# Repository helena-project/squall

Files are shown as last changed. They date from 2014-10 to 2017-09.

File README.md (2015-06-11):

Squall
======

Squall is a low cost, 1 inch round BLE sensor tag based on the Nordic
nRF51822 BLE / Cortex M0 SoC. It is designed to be the basis for experimenting
with BLE tag platforms.

### Squall Versions

Squall comes in two flavors: a stripped down version with only the essentials
that has a raw cost just over $5. This includes the SoC, an antenna, expansion
headers, and a battery clip. This version is targeted towards sensor deployments
where a low cost per device is essential to permit larger deployments.

The second version adds USB support so that the nRF51822 can be programmed
with a serial bootloader, and adds a reset button and 32 kHz crystal. This
design is intended to be easier to get started with as it only requires
a USB connection to program. It also supports a rechargeable battery that
will charge over USB.

### Hardware Tools

To aid developing with Squall, there is a
[breakout board](/hardware/squall-breakout/rev_b) that makes it easier to debug
signals and program the board.

To program Squall over JTAG, there is an
[adapter board](https://github.com/lab11/nrf51-tools/tree/master/hardware/jlink_to_tag/rev_b)
that adapts the J-Link JTAG 20-pin header to the much smaller
[tag connect](http://www.tag-connect.com/catalog/6) header.

Daughter Boards
---------------

Squall is designed to be a base BLE platform with shields on top. A couple
shields have been developed:

- [Rain](/hardware/rain) - Sensing platform for wearable exploration.
- [BLEES](https://github.com/lab11/blees) - Environmental sensing platform.

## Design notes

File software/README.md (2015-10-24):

Setting Up The nRF51822
=======================

This guide explains how to get going with running code on nRF51822 based
platforms.

Setup
-----

1. Make sure you have the [arm-none-eabi-gcc](https://launchpad.net/gcc-arm-embedded)
toolchain. You just need the binaries for your platform.

1. Get the [Segger flashing tools](http://www.segger.com/jlink-software.html)
for your platform.

Install an Application
----------------------

1. Now compile and load the application code. This will also
load the softdevice onto the nRF if needed.

        make flash

    For platforms that are not Squall:

        make flash TARGET=nrf6310

    Choices:

        NRF6310
        PCA10000
        PCA10001
        PCA10003
        SQUALL
        
    If you have multiple JLink devices, you can specify which one
    to use like this:
    
        SEGGER_SERIAL=<serial num> make flash

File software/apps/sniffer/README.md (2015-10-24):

Sniffer BLE App
===============

This app blinks the LED everytime it receives an advertisement.

It uses the central role on the S120 softdevice.

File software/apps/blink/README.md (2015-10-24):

Blink App
=========

Blink the LED on Squall.

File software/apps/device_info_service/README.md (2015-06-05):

Service Example
===============

This is a simple base application that continually advertises and has a device 
information service.

This app should be a good starting point for providing a service.

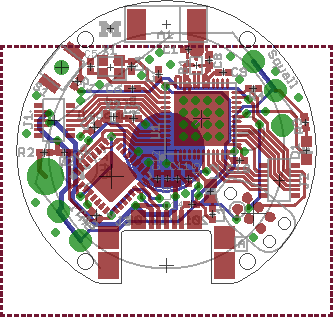
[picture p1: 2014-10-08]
hardware/squall/rev_a/squall_pcb.png

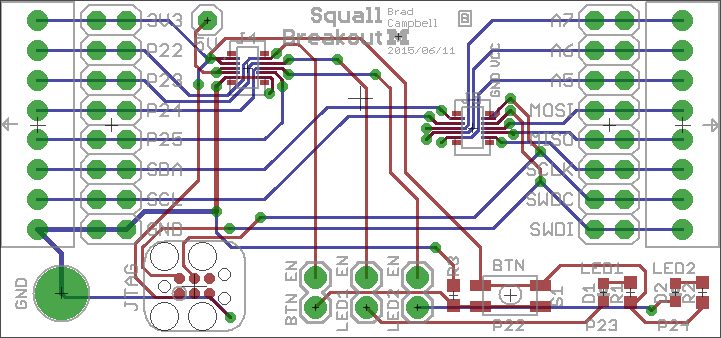
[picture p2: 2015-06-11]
hardware/squall-breakout/rev_b/squall-breakout_pcb.png

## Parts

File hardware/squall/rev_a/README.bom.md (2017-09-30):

Squall BOM
==========

Squall comes in two possible configurations, A and B. Configuration A is
cheaper. It does not include any USB integration, just the Bluetooth.

The files `squall_bom.LEGACY` present these configurations as priced out
in 2014 with the original design. A handful of passives have been obsoleted
since then, they are not hard to replace.

The files `squall_bom.2017-09.ConfigurationB` are an updated BOM from a
manufacturing run in fall '17 for the full-featured configuration.

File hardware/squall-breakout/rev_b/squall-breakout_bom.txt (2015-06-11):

# Bill of Materials
# Converted from squall-breakout_bom.xlsx
# Generated by bom_to_text.py

Qty  Value                   Device                  Package            Parts         Description                                                    DIGIKEY       MOUSER               NEWARK
2                            LED0603                 LED-0603           D1, D2        LEDs                                                                                              
2    SQUALL_HEADER           SQUALL_HEADER           SQUALL_HEADER      J1            Header for a sensor board on top of the Squall BLE tag board.  H11617CT-ND                        
2                            PINHD-2X8               2X08               J2, J3        PIN HEADER                                                     609-3364-ND   649-68602-116HLF     20M2833
2    HIROSE-DF40C-10DP-0.4V  HIROSE-DF40C-10DP-0.4V  2X5/SMD/0.4MM      J4, J5        DF40 Series Header - 0.4MM Pitch                               H11616CT-ND   798-DF40C10DP0.4V51  68X2585
1                            PINHD-1X1               1X01               J6            PIN HEADER                                                     A107006-ND                         
2    SCREW-TERMINAL_8_0.100  SCREW-TERMINAL_8_0.100  CONN_BLOCK_8       J7, J8        8x 0.100 in screw terminal block                               277-1279-ND   651-1725711          71C4111
3                            JUMPER-2PTH             1X02               J9, J10, J11  Jumper                                                         3M9447-ND                          
2    470                     R-US_R0603              R0603              R1, R2        RESISTOR, American symbol                                                                         
1    10k                     R-US_R0603              R0603              R3            RESISTOR, American symbol                                                                         
1    EVQP2                   EVQP2                   EVQP2              S1            SWITCH TACTILE SPST-NO 0.02A 15V                               P11084SCT-ND                       
1    TEST_POINT_0.112IN      TEST_POINT_0.112IN      TESTPOINT_0.112IN  TP1           Solder terminal, turreted                                                                         40F6015

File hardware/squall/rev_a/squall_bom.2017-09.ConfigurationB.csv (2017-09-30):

# Bill of Materials
# Converted from {}
# Generated by bom_to_text.py
#
Qty | Parts | Do Not Insert | Can Substitute? | Value | Device | Package | DESCRIPTION | DIGIKEY | MANUFACTURER | MOUSER | MPN | NEWARK | OC_FARNELL | OC_NEWARK | RICHARDSON_RFPD
1 | A1 |  |  | FRACTUS-2.4GHZ-FR05-S1-N-0-102 | FRACTUS-2.4GHZ-FR05-S1-N-0-102 | FRACTUS-ANTENNA-FR05-S1-N-0-102 | Fractus Compact Reach XtendTM chip antenna is engineered specifically for Bluetooth, |  | RichardsonRFPD |  | FR05-S1-N-0-102 |  |  |  | FR05-S1-N-0102B
1 | B1 |  |  | BAL-NRF01D3 | BAL-NRF01D3 | BAL-NRF01D3 | 50 ohm nominal input / conjugate match balun to nRF51422-QFAA, | 497-13637-1-ND |  | 511-BAL-NRF01D3 | BAL-NRF01D3
1 | BAT1 | X |  | BAT-HLD-002-THM | BAT-HLD-002-THM | BAT-HLD-002-THM | RETAINER BATT CR2016 PC PINS | BAT-HLD-002-THM-ND |  | 712-BAT-HLD-002-THM
1 | BAT2 | X |  | ML-2020/H1C | ML-2020/H1C | ML-2020/H1C | BATT LITH COIN 3V RECHARGE PINS 45mAh | P047-ND |  | 658-ML-2020/H1CN
1 | C1 |  | Y | 0.8pF | CAPACITOR | 0402_CAP | CAP CER 0.8PF 50V C0G/NP0 0402 | 490-6269-1-ND | Murata |  | GRM1555C1HR80BA01D
4 | C2, C3, C4, C5 |  | Y | 12pF | CAPACITOR | 0402_CAP | CAP CER 12PF 50V C0G/NP0 0402 | 490-6197-1-ND | Murata |  | GRM1555C1H120GA01D
2 | C6, C7 |  | Y | 1nF | CAPACITOR | 0402_CAP | CAP CER 1000PF 50V X7R 0402 | 490-1303-1-ND | Murata |  | GRM155R71H102KA01D
1 | C8 |  | Y | 2.2nF | CAPACITOR | 0402_CAP | CAP CER 2200PF 25V 10% X7R 0402 | 490-5419-1-ND | Murata |  | GRM155R71E222KA01D
1 | C9 |  | Y | 47nF | CAPACITOR | 0402_CAP | CAP CER 0.047UF 16V X7R 0402 | 445-1264-1-ND | TDK |  | C1005X7R1C473K050BC
4 | C10, C11, C12, C13 |  | Y | 0.1uF | CAPACITOR | 0402_CAP | CAP CER 0.1UF 10V X5R 0402 | 490-1318-1-ND | Murata |  | GRM155R61A104KA01D
1 | C14 |  | Y | 1uF | CAPACITOR | 0402_CAP | 1µF ±10% 6.3V Ceramic Capacitor X7R 0402 (1005 Metric) | 1276-1513-1-ND | Samsung |  | CL05B105KQ5NQNC
1 | C15 |  | Y | 4.7uF | CAPACITOR | 0402_CAP | CAP CER 4.7UF 6.3V X5R 0402 | 445-5947-1-ND | TDK |  | C1005X5R0J475K050BC
1 | D1 |  | Y | BLUE | LED0603 | LED-0603 | LED BLUE CLEAR 0603 SMD | 160-1827-1-ND | Lite-On |  | LTST-C193TBKT-5A
1 | D2 |  | Y | DIODE | DIODE | 0402_DIODE | DIODE SCHOTTKY 30V 0.1A 0402 | 641-1271-1-ND | Comchip | 750-CDBQR0130L | CDBQR0130L
2 | J1, J2 |  |  | HIROSE-DF40C-10DP-0.4V | HIROSE-DF40C-10DP-0.4V | 2X5/SMD/0.4MM | DF40 Series Header - 0.4MM Pitch | H11616CT-ND |  | 798-DF40C10DP0.4V51 | DF40C-10DP-0.4V(51) | 68X2585
1 | J3 |  |  | MICRO_USB_B_JST_MC5BR3-M404-4S | MICRO_USB_B_JST_MC5BR3-M404-4S | USB_MICRO_B-JST-MC5BR3-M404-4S-TB | Micro USB B mid mount | 455-2567-2-ND |  | 53X3655 | UB-MC5BR3-M404-4S-TB NMP
1 | J4 | X |  | TC2030-JLINK-NL | TC2030-JLINK-NL | TC2030-IDC-NL |  | - | - | - | -
1 | L1 |  |  | 15nH | INDUCTOR0402 | 0402_CAP | FIXED IND 15NH 320MA 460 MOHM | 587-1521-1-ND | Taiyo Yuden |  | HK100515NJ-T
1 | L2 |  |  | 10uH | INDUCTOR0603 | 0603_CAP | FIXED IND 10UH 50MA 900 MOHM SMD | 490-4025-1-ND | Murata |  | LQM18FN100M00D
1 | L3 |  | Y |  | INDUCTOR0402 | 0402_CAP | FERRITE BEAD 30 OHM 0402 1LN | 445-2979-1-ND | TDK Corporation |  | MPZ1005S300CT000
2 | R1, R2 |  | Y | 150 | RESISTOR | 0402_RES | RES SMD 150 OHM 1% 1/16W 0402 | RHM150CDCT-ND | Rohm |  | MCR01MRTF1500
1 | R3 |  | Y | 1k | RESISTOR | 0402_RES | RES SMD 1K OHM 5% 1/16W 0402 | 1276-4376-1-ND | Samsung |  | RC1005J102CS
1 | R4 |  | Y | 12k | RESISTOR | 0402_RES | RES SMD 12K OHM 1% 1/16W 0402 | 1276-4122-1-ND | Samsung |  | RC1005F123CS
1 | S1 |  |  | B3U-3000P-B | B3U-3000P-B | B3U-3000P-B |  | SW1256CT-ND |  |  | B3U-3000P-B
1 | U1 |  |  | NRF51822QF | NRF51822QF | QFN-48-6MM | Multiprotocol Bluetooth® 4.0 low energy/2.4 GHz RF SoC | 1490-1032-1-ND | Nordic | 949-NRF51822-QFAB-R7 | NRF51822-QFAB-R7
1 | U2 |  |  | FT232RQ | FT232RQ | QFN32 | Source: http://www.ftdichip.com/Documents/DataSheets/DS_FT232R_v104.pdf |  |  |  | FT232RQ |  | 1146033 | 91K9919
1 | X1 |  |  | 16MHz | TXC-8Y | TXC-8Y | CRYSTAL 16.0000MHZ 8PF SMD | 887-2003-1-ND | TXC |  | 8Y-16.000MAAV-T
1 | X2 |  |  | ABS05-32.768KHZ-9-T | ABS05-32.768KHZ-9-T | ABS05 | 32.768kHz Crystal | 535-11897-1-ND
 | Note: Any part marked "Can Substitue" can be substituted for any equal size/value parts

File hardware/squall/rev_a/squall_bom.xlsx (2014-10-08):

Qty | Value | Device | Package | Parts | Description | DIGIKEY | MOUSER | NEWARK | RICHARDSON_RFPD | Price Each (1000) | Quantity (A) | Cost (A) | Quantity (B) | Cost (B)
1 | FRACTUS-2.4GHZ-FR05-S1-N-0-102 | FRACTUS-2.4GHZ-FR05-S1-N-0-102 | FRACTUS-ANTENNA-FR05-S1-N-0-102 | A1 | Fractus Compact Reach XtendTM chip antenna is engineered specifically for Bluetooth, |  |  |  | FR05-S1-N-0102B | 0.63 | 1 | 0.63 | 1 | 0.63
1 | BAL-NRF01D3 | BAL-NRF01D3 | BAL-NRF01D3 | B1 | 50 ohm nominal input / conjugate match balun to nRF51422-QFAA, | 497-13637-1-ND | 511-BAL-NRF01D3 |  |  | 0.337 | 1 | 0.337 | 1 | 0.337
1 | BAT-HLD-002-THM | BAT-HLD-002-THM | BAT-HLD-002-THM | BAT1 | RETAINER BATT CR2025/2032 PC PIN | BAT-HLD-001-THM-ND |  |  |  | 0.20125 | 1 | 0.20125 |  | 0
1 | ML-2020/H1C | ML-2020/H1C | ML-2020/H1C | BAT2 | BATT LITH COIN 3V RECHARGE PINS 45mAh | P047-ND | 658-ML-2020/H1CN |  |  | 1.4025 |  | 0 | 1 | 1.4025
1 | 0.8pF | CAPACITOR | 0402_CAP | C1 | 0402 Capacitor | 490-6269-1-ND |  |  |  | 0.0127 | 1 | 0.0127 | 1 | 0.0127
4 | 12pF | CAPACITOR | 0402_CAP | C2, C3, C4, C5 | 0402 Capacitor | 490-6197-1-ND |  |  |  | 0.0178 | 2 | 0.0356 | 4 | 0.0712
2 | 1nF | CAPACITOR | 0402_CAP | C6, C7 | 0402 Capacitor | 490-1303-1-ND |  |  |  | 0.01009 | 2 | 0.02018 | 2 | 0.02018
1 | 2.2nF | CAPACITOR | 0402_CAP | C8 | 0402 Capacitor | 490-5419-1-ND |  |  |  | 0.0127 | 1 | 0.0127 | 1 | 0.0127
1 | 47nF | CAPACITOR | 0402_CAP | C9 | 0402 Capacitor | 445-1264-1-ND |  |  |  | 0.0151 | 1 | 0.0151 | 1 | 0.0151
1 | 0.1uF | CAPACITOR | 0402_CAP | C10 | 0402 Capacitor | 445-4952-1-ND |  |  |  | 0.0136 | 1 | 0.0136 | 1 | 0.0136
3 | 0.1uF | CAPACITOR | 0402_CAP | C11, C12, C13 | 0402 Capacitor | 490-1318-6-ND |  |  |  | 0.01 |  | 0 | 3 | 0.03
1 | 1uF | CAPACITOR | 0402_CAP | C14 | 0402 Capacitor | 1276-1513-1-ND |  |  |  | 0.058 |  | 0 | 1 | 0.058
1 | 4.7uF | CAPACITOR | 0402_CAP | C15 | 0402 Capacitor | 445-5947-1-ND |  |  |  | 0.122 |  | 0 | 1 | 0.122
1 | BLUE | LED0603 | LED-0603 | D1 | LED 468NM BLUE CLEAR 0603 SMD | 160-1647-1-ND |  |  |  | 0.0925 | 1 | 0.0925 | 1 | 0.0925
1 | DIODE | DIODE | 0402_DIODE | D2 | DIODE SCHOTTKY 30V 0.1A 0402 | 641-1271-1-ND | 750-CDBQR0130L |  |  | 0.11 |  | 0 | 1 | 0.11
2 | HIROSE-DF40C-10DP-0.4V | HIROSE-DF40C-10DP-0.4V | 2X5/SMD/0.4MM | J1, J2 | DF40 Series Header - 0.4MM Pitch | H11616CT-ND | 798-DF40C10DP0.4V51 | 68X2585 |  | 0.38815 | 2 | 0.7763 | 2 | 0.7763
1 | MICRO_USB_B_JST_MC5BR3-M404-4S | MICRO_USB_B_JST_MC5BR3-M404-4S | USB_MICRO_B-JST-MC5BR3-M404-4S-TB | J3 | Micro USB B mid mount | 455-2567-2-ND | 53X3655 |  |  | 0.60558 |  | 0 | 1 | 0.60558
1 | 15nH | INDUCTOR0402 | 0402_CAP | L1 | INDUCTOR HI FREQ 15NH 5% 0402 | 587-1521-1-ND |  |  |  | 0.034 | 1 | 0.034 | 1 | 0.034
1 | 10uH | INDUCTOR0603 | 0603_CAP | L2 | INDUCTOR 10UH 50MA 0603 | 490-4025-1-ND |  |  |  | 0.07434 | 1 | 0.07434 | 1 | 0.07434
1 |  | INDUCTOR0402 | 0402_CAP | L3 | FERRITE CHIP 30 OHM 1.7A 0402 | 445-2979-1-ND |  |  |  | 0.0334 |  | 0 | 1 | 0.0334
2 | 150 | RESISTOR | 0402_RES | R1, R2 | Resistor | RHM150CDCT-ND |  |  |  | 0.00933 |  | 0 | 2 | 0.01866
1 | 1k | RESISTOR | 0402_RES | R3 | Resistor | RHM1.0KCECT-ND |  |  |  | 0.00933 | 1 | 0.00933 | 1 | 0.00933
1 | 12k | RESISTOR | 0402_RES | R4 | Resistor | RHM12.0KCDCT-ND |  |  |  | 0.00933 | 1 | 0.00933 | 1 | 0.00933
1 | B3U-3000P-B | B3U-3000P-B | B3U-3000P-B | S1 | SWITCH TACTILE SPST-NO 0.05A 12V | SW1256CT-ND |  |  |  | 0.66414 |  | 0 | 1 | 0.66414
1 | NRF51822QF | NRF51822QF | QFN-48-6MM | U1 | Multiprotocol Bluetooth® 4.0 low energy/2.4 GHz RF SoC 256K | 1490-1031-1-ND |  |  |  | 2.31 | 1 | 2.31 | 1 | 2.31
1 | FT232RQ | FT232RQ | QFN32 | U2 | IC USB FS SERIAL UART 32-QFN | 768-1008-1-ND |  | 91K9919 |  | 3.301 |  | 0 | 1 | 3.301
1 | 16MHz | TXC-8Y | TXC-8Y | X1 | CRYSTAL 16MHZ 8PF SMD | 887-2003-1-ND |  |  |  | 0.782 | 1 | 0.782 | 1 | 0.782
1 | ABS05-32.768KHZ-9-T | ABS05-32.768KHZ-9-T | ABS05 | X2 | 32.768kHz Crystal | 535-11897-1-ND |  |  |  | 1.061 |  | 0 | 1 | 1.061
 |  |  |  |  | BATTERY LITHIUM COIN 3V 20MM CR2032 | P189-ND |  |  |  | 0.15579 | 1 | 0.15579
 |  |  |  |  |  |  |  |  |  |  |  | 5.52172 |  | 12.60656

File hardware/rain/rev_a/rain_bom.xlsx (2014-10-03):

Qty | Value | Device | Package | Parts | Description | DIGIKEY | PRECISION_MICRODRIVES
1 | 10nF | CAPACITOR | 0402_CAP | C1 | 0402 Capacitor | 490-1312-1-ND
7 | 0.1uF | CAPACITOR | 0402_CAP | C2, C3, C4, C5, C6, C7, C8 | 0402 Capacitor | 490-1318-1-ND
1 | 10uF | CAPACITOR | 0402_CAP | C9 | 0402 Capacitor | 445-8919-1-ND
1 | 22uF | CAP_POL0603 | CAP0603 | C10 | 0603 Tantalum Capacitor | 511-1493-1-ND
3 | SFH4056 | SFH4056 | SFH4056 | D1, D2, D3 | LED IR EMITTER 850NM | 475-3042-1-ND
1 | DIODE | DIODE | 0402_DIODE | D4 |  | 641-1277-1-ND
2 | SQUALL_HEADER | SQUALL_HEADER | SQUALL_HEADER | J1 | Header for a sensor board on top of the Squall BLE tag board. | H11617CT-ND
1 |  | PINHD-2X2 | 2X02 | J2 | PIN HEADER | 609-3201-ND
1 | 308-100 | 308-100 | 308-100 | M1 | Pico Vibe |  | 308-100
1 | ROHM-NPN-2SC5662 | ROHM-NPN-2SC5662 | VMT3 | Q1 |  | 2SC5662T2LPCT-ND
1 | 30 | RESISTOR0402_RES | 0402_RES | R1 | Resistor | RHM30CECT-ND
1 | 33 | RESISTOR0402_RES | 0402_RES | R2 | Resistor | RHM33CECT-ND
1 | 1k | RESISTOR0402_RES | 0402_RES | R3 | Resistor | RHM1.0KCECT-ND
2 | 10k | RESISTOR0402_RES | 0402_RES | R4, R5 | Resistor | RHM10.0KCDCT-ND
1 | LPS331AP | LPS331AP | HCLGA-16/3MM | U1 | IC PRESSURE SENSOR PIEZO 16HCLGA | 497-12927-1-ND
1 | MPU-9250 | MPU-9250 | QFN-24/3MM | U2 | GYRO/ACCEL/COMPASS/9-AXIS | 1428-1019-1-ND
1 | SI1147 | SI1147 | QFN-10/2MM | U3 | SENSOR DGTL UV INDEX 10QFN | 336-2624-1-ND
1 | SI7021 | SI7021 | DFN-6/3MM | U4 | IC TEMP SENSOR RH 2% DFN | 336-2542-1-ND

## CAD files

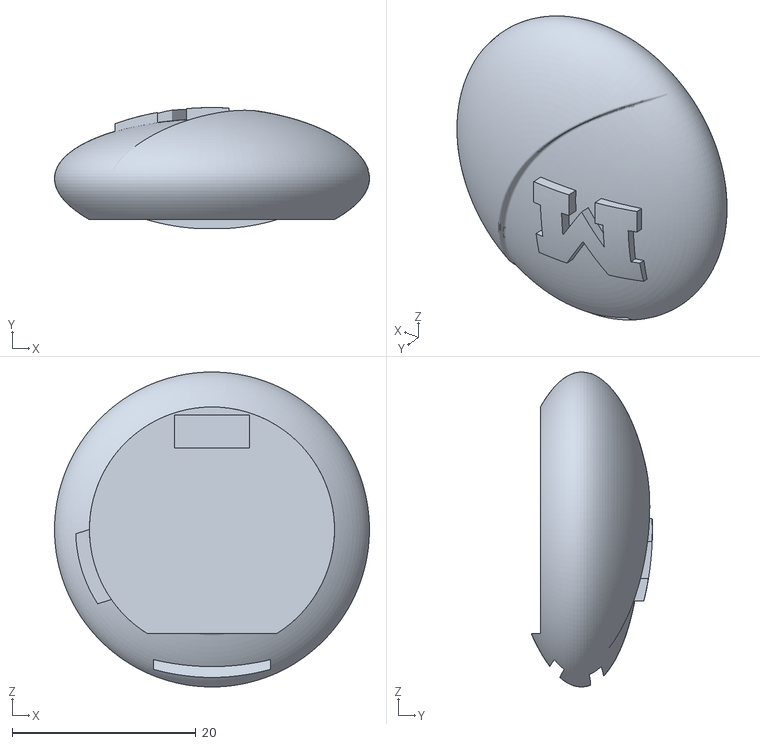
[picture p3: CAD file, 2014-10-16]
cases/squall_base_case_top_5.stl
34.3 x 13.2 x 34.3

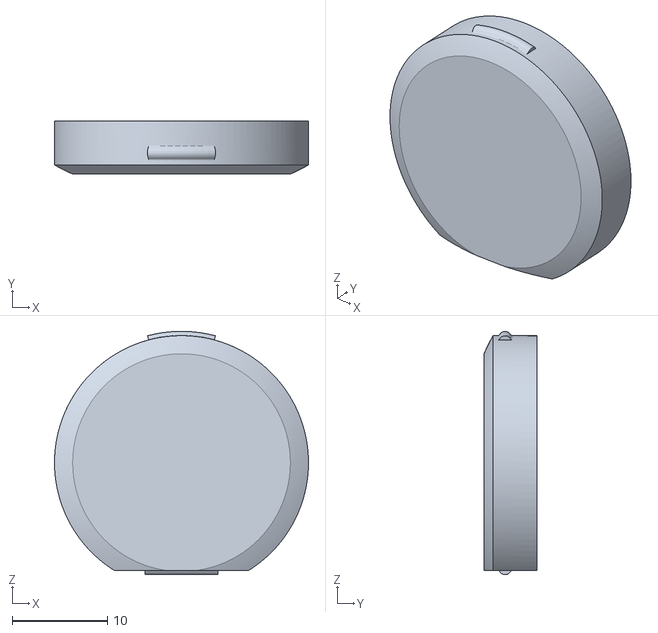
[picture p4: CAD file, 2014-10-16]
cases/squall_base_case_bottom_5.stl
26.7 x 5.59 x 25.5

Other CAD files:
cases/case.ipt
cases/case_bottom.ipt

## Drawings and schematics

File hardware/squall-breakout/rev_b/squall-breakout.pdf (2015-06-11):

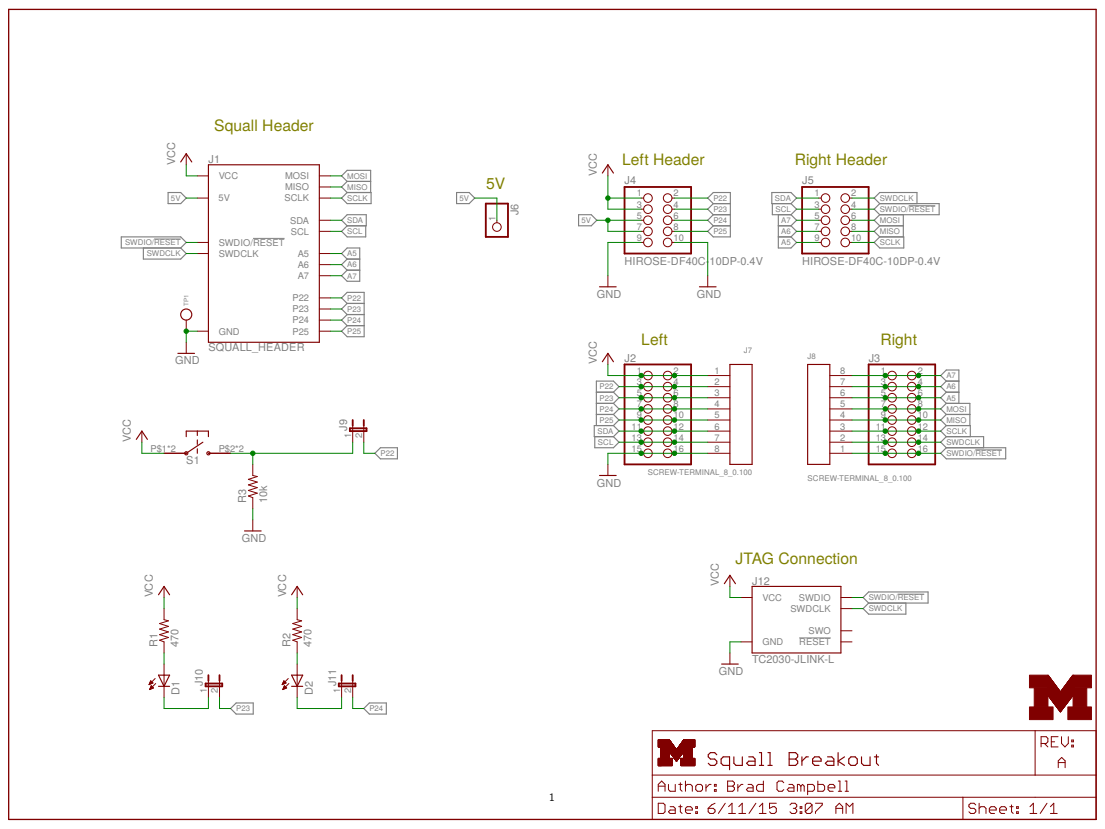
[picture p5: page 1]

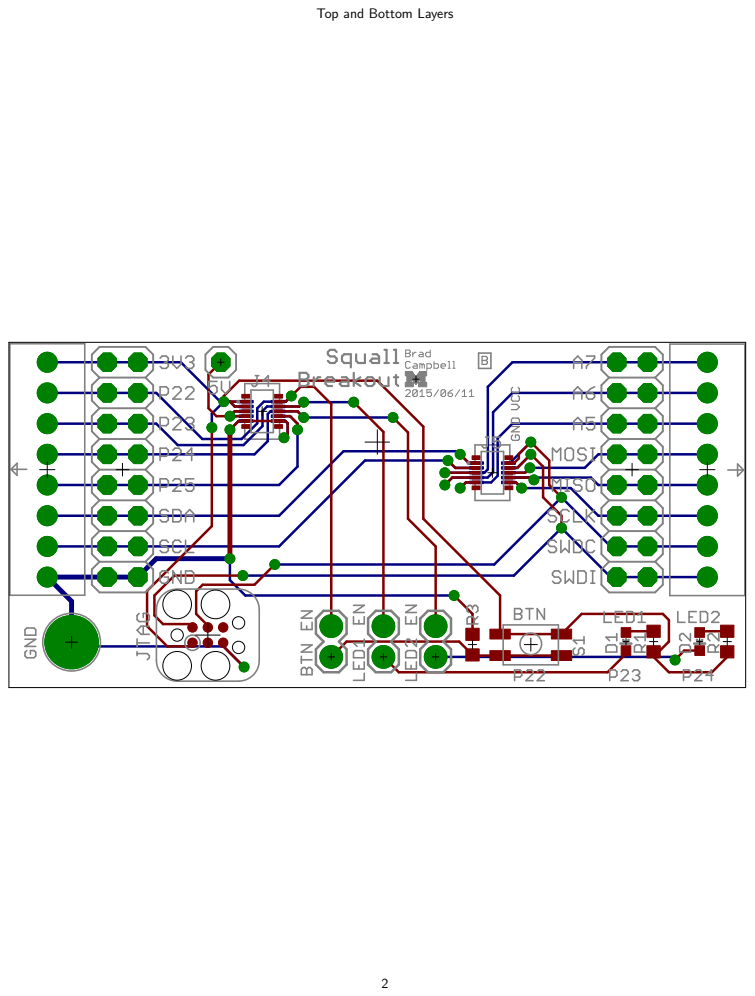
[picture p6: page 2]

Top and Bottom Layers

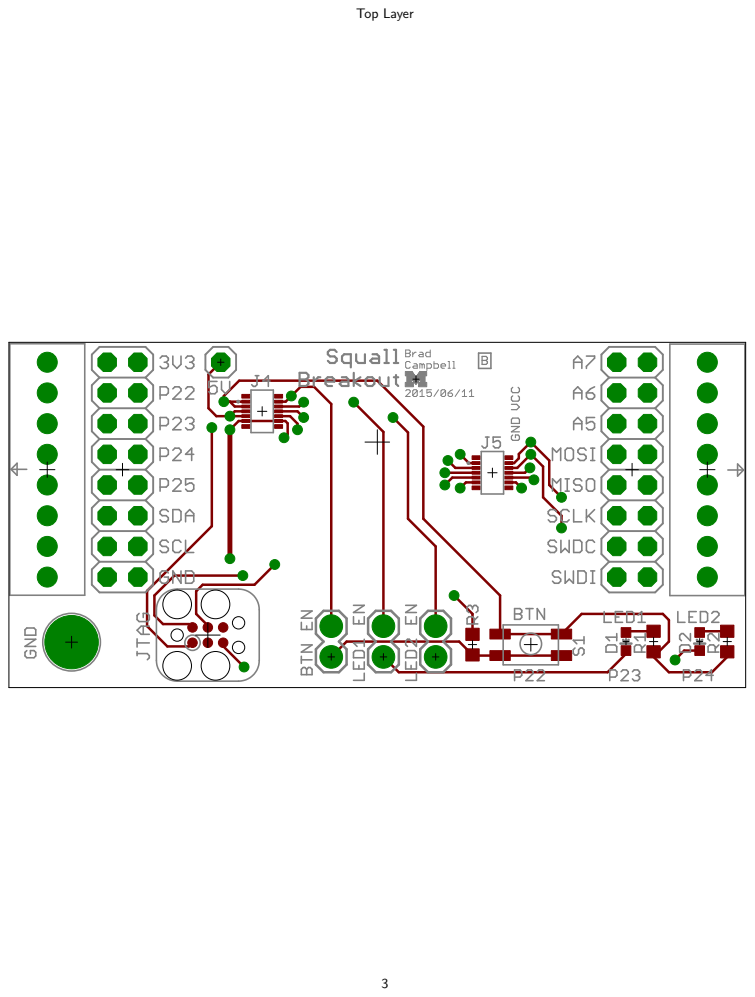
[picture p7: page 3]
Top Layer

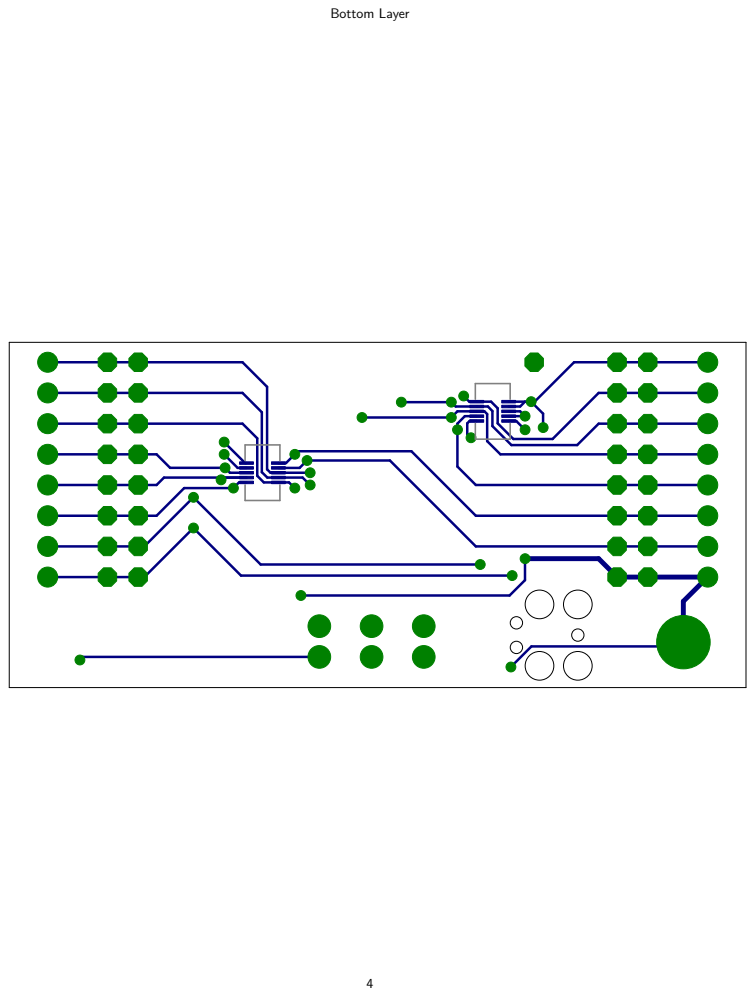
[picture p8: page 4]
Bottom Layer

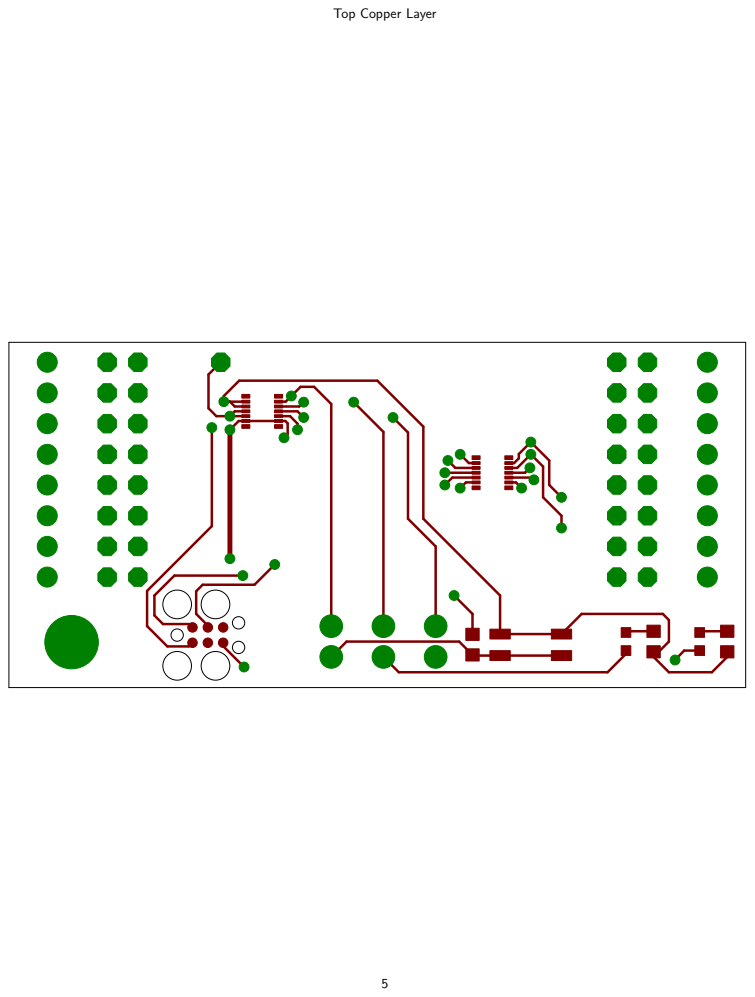
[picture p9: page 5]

Top Copper Layer

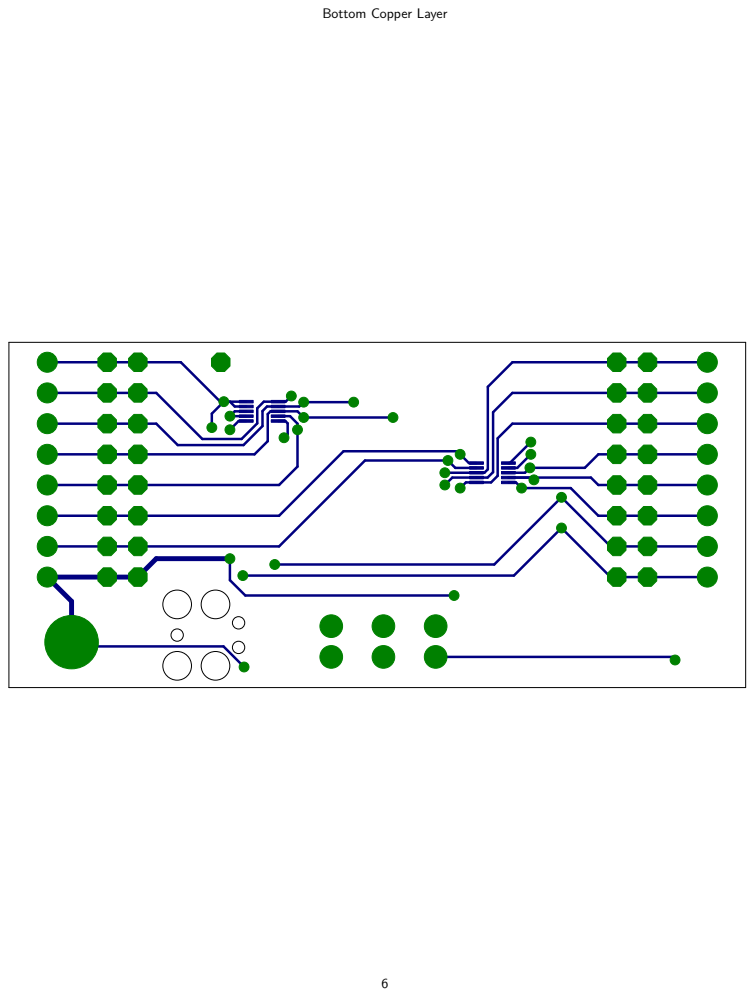
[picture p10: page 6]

Bottom Copper Layer

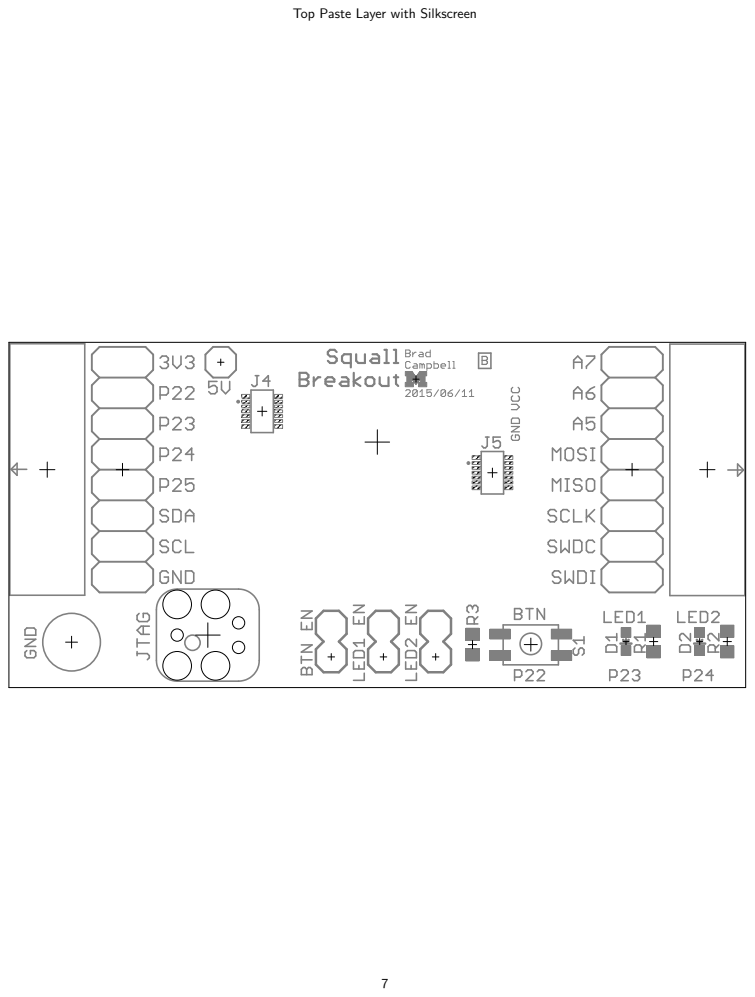
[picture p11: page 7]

Top Paste Layer with Silkscreen

Bottom Paste Layer with Silkscreen

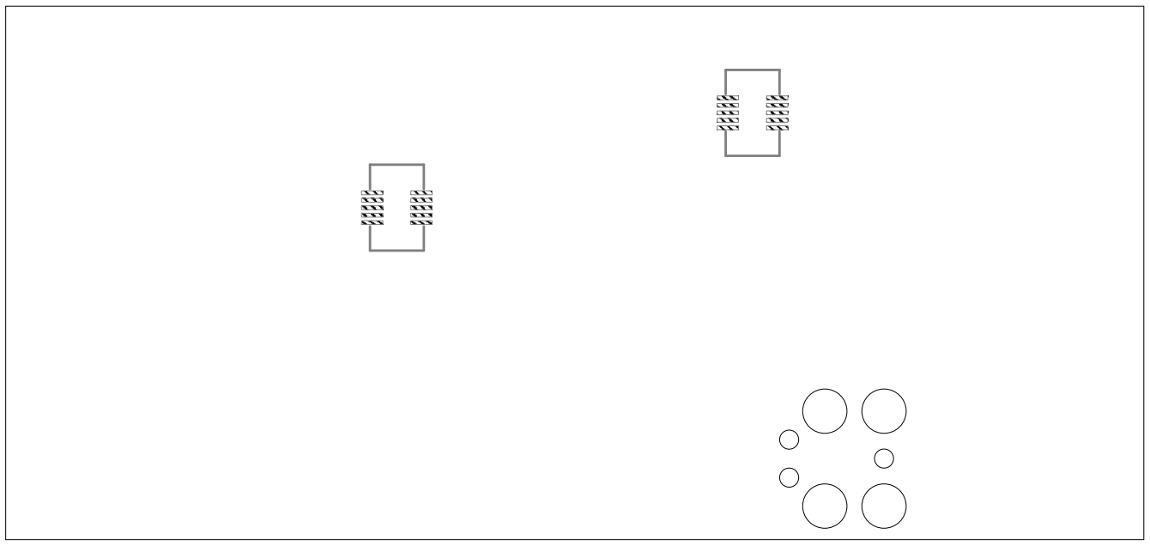
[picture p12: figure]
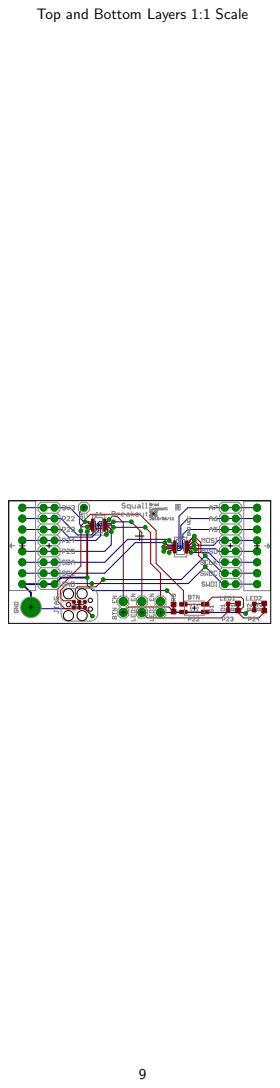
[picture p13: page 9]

Top and Bottom Layers 1:1 Scale

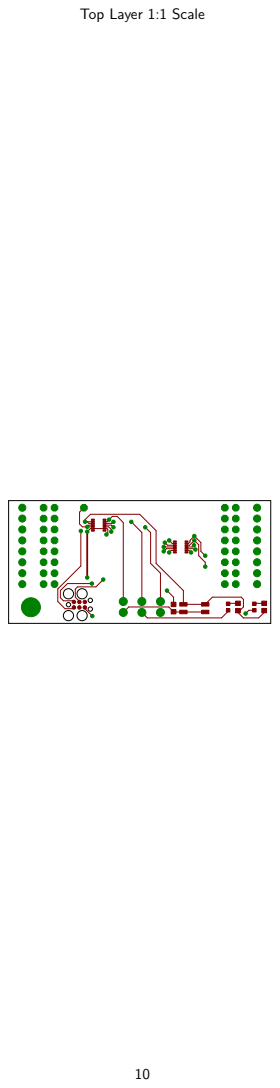
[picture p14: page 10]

Top Layer 1:1 Scale

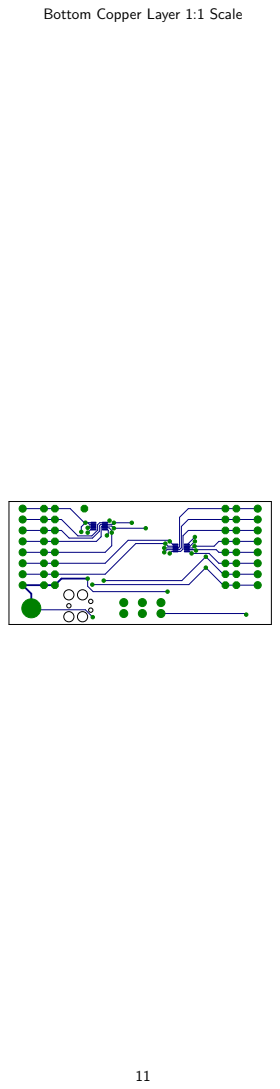
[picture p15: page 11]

Bottom Copper Layer 1:1 Scale

### Sheet1

Qty Value | Device | Package | Parts
2 | LED0603 | LED-0603 | D1, D2
2 SQUALL_HEADER | SQUALL_HEADER | SQUALL_HEADER | J1
2 | PINHD-2X8 | 2X08 | J2, J3
2 HIROSE-DF40C-10DP-0.4V | HIROSE-DF40C-10DP-0.4V | 2X5/SMD/0.4MM | J4, J5
1 | PINHD-1X1 | 1X01 | J6
2 SCREW-TERMINAL_8_0.100 SCREW-TERMINAL_8_0.100 CONN_BLOCK_8 | J7, J8
3 | JUMPER-2PTH | 1X02 | J9, J10, J11
2 470 | R-US_R0603 | R0603 | R1, R2
1 10k | R-US_R0603 | R0603 | R3
1 EVQP2 | EVQP2 | EVQP2 | S1
1 TEST_POINT_0.112IN | TEST_POINT_0.112IN | TESTPOINT_0.112IN TP1

### Sheet1

Description | DIGIKEY | MOUSER
LEDs
Header for a sensor board on top of the Squall BLE tag board. H11617CT-ND
PIN HEADER | 609-3364-ND | 649-68602-116HLF
DF40 Series Header - 0.4MM Pitch | H11616CT-ND 798-DF40C10DP0.4V51
PIN HEADER | A107006-ND
8x 0.100 in screw terminal block | 277-1279-ND | 651-1725711
Jumper | 3M9447-ND
RESISTOR, American symbol
RESISTOR, American symbol
SWITCH TACTILE SPST-NO 0.02A 15V | P11084SCT-ND
Solder terminal, turreted

### Sheet1

NEWARK

20M2833
68X2585

71C4111

40F6015

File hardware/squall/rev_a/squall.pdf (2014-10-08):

Left Header | Right Header

## JTAG Connection

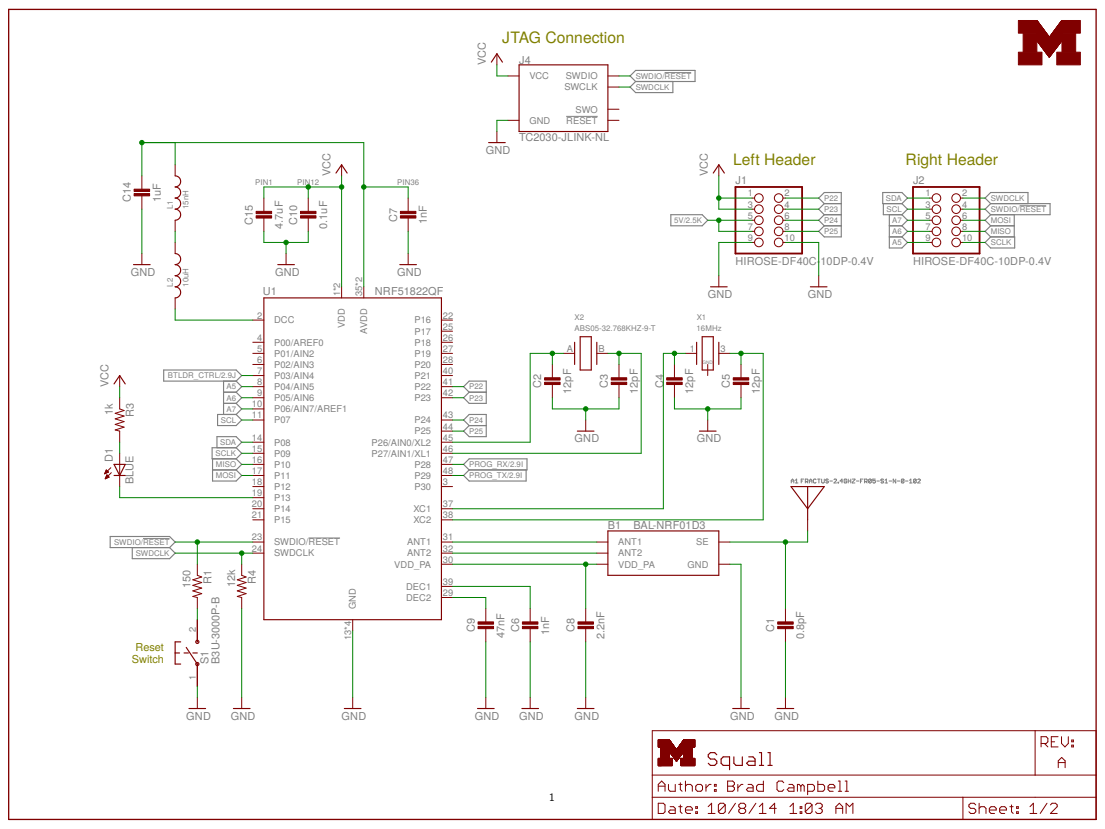
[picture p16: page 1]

## Batteries


Note: Only one battery can be connected at a time.
If BAT1 is connected, do not populate D2 or R2.
If BAT2 is connected, D2 and R2 must be populated for recharging.

FTDI Circuit for UART Programming and Communication


Top and Bottom Layers

Top Layer

Bottom Layer


Top Copper Layer


Bottom Copper Layer


Top Paste Layer with Silkscreen


Bottom Paste Layer with Silkscreen


Top and Bottom Layers 1:1 Scale

Top Layer 1:1 Scale


Bottom Copper Layer 1:1 Scale

### Sheet1

Qty Value | Device
1 FRACTUS-2.4GHZ-FR05-S1-N-0-102 | FRACTUS-2.4GHZ-FR05-S1-N-0-102
1 BAL-NRF01D3 | BAL-NRF01D3
1 BAT-HLD-002-THM | BAT-HLD-002-THM
1 ML-2020/H1C | ML-2020/H1C
1 0.8pF | CAPACITOR
4 12pF | CAPACITOR
2 1nF | CAPACITOR
1 2.2nF | CAPACITOR
1 47nF | CAPACITOR
1 0.1uF | CAPACITOR
3 0.1uF | CAPACITOR
1 1uF | CAPACITOR
1 4.7uF | CAPACITOR
1 BLUE | LED0603
1 DIODE | DIODE
2 HIROSE-DF40C-10DP-0.4V | HIROSE-DF40C-10DP-0.4V
1 MICRO_USB_B_JST_MC5BR3-M404-4S MICRO_USB_B_JST_MC5BR3-M404-4S
1 15nH | INDUCTOR0402
1 10uH | INDUCTOR0603
1 | INDUCTOR0402
2 150 | RESISTOR
1 1k | RESISTOR
1 12k | RESISTOR
1 B3U-3000P-B | B3U-3000P-B
1 NRF51822QF | NRF51822QF
1 FT232RQ | FT232RQ
1 16MHz | TXC-8Y
1 ABS05-32.768KHZ-9-T | ABS05-32.768KHZ-9-T

### Sheet1

Package | Parts
FRACTUS-ANTENNA-FR05-S1-N-0-102 | A1
BAL-NRF01D3 | B1
BAT-HLD-002-THM | BAT1
ML-2020/H1C | BAT2
0402_CAP | C1
0402_CAP | C2, C3, C4, C5
0402_CAP | C6, C7
0402_CAP | C8
0402_CAP | C9
0402_CAP | C10
0402_CAP | C11, C12, C13
0402_CAP | C14
0402_CAP | C15
LED-0603 | D1
0402_DIODE | D2
2X5/SMD/0.4MM | J1, J2
USB_MICRO_B-JST-MC5BR3-M404-4S-TB J3
0402_CAP | L1
0603_CAP | L2
0402_CAP | L3
0402_RES | R1, R2
0402_RES | R3
0402_RES | R4
B3U-3000P-B | S1
QFN-48-6MM | U1
QFN32 | U2
TXC-8Y | X1
ABS05 | X2

### Sheet1

Description
Fractus Compact Reach XtendTM chip antenna is engineered specifically for Bluetooth, 50 ohm nominal input / conjugate match balun to nRF51422-QFAA,
RETAINER BATT CR2025/2032 PC PIN
BATT LITH COIN 3V RECHARGE PINS 45mAh
0402 Capacitor
0402 Capacitor
0402 Capacitor
0402 Capacitor
0402 Capacitor
0402 Capacitor
0402 Capacitor
0402 Capacitor
0402 Capacitor
LED 468NM BLUE CLEAR 0603 SMD DIODE SCHOTTKY 30V 0.1A 0402 DF40 Series Header - 0.4MM Pitch Micro USB B mid mount
INDUCTOR HI FREQ 15NH 5% 0402 INDUCTOR 10UH 50MA 0603
FERRITE CHIP 30 OHM 1.7A 0402 Resistor
Resistor
Resistor
SWITCH TACTILE SPST-NO 0.05A 12V
Multiprotocol Bluetooth® 4.0 low energy/2.4 GHz RF SoC 256K IC USB FS SERIAL UART 32-QFN
CRYSTAL 16MHZ 8PF SMD
32.768kHz Crystal
BATTERY LITHIUM COIN 3V 20MM CR2032

### Sheet1

DIGIKEY | MOUSER | NEWARK RICHARDSON_RFPD Price Each (1000)
FR05-S1-N-0102B | 0.63
497-13637-1-ND | 511-BAL-NRF01D3 | 0.337
BAT-HLD-001-THM-ND | 0.20125
P047-ND | 658-ML-2020/H1CN | 1.4025
490-6269-1-ND | 0.0127
490-6197-1-ND | 0.0178
490-1303-1-ND | 0.01009
490-5419-1-ND | 0.0127
445-1264-1-ND | 0.0151
445-4952-1-ND | 0.0136
490-1318-6-ND | 0.01
1276-1513-1-ND | 0.058
445-5947-1-ND | 0.122
160-1647-1-ND | 0.0925
641-1271-1-ND | 750-CDBQR0130L | 0.11
H11616CT-ND | 798-DF40C10DP0.4V51 68X2585 | 0.38815
455-2567-2-ND | 53X3655 | 0.60558
587-1521-1-ND | 0.034
490-4025-1-ND | 0.07434
445-2979-1-ND | 0.0334
RHM150CDCT-ND | 0.00933
RHM1.0KCECT-ND | 0.00933
RHM12.0KCDCT-ND | 0.00933
SW1256CT-ND | 0.66414
1490-1031-1-ND | 2.31
768-1008-1-ND | 91K9919 | 3.301
887-2003-1-ND | 0.782
535-11897-1-ND | 1.061
P189-ND | 0.15579

### Sheet1

Quantity (A) Cost (A) | Quantity (B) Cost (B)
1 | 0.63 | 1 | 0.63
1 | 0.337 | 1 | 0.337
1 | 0.20125 | | 0
| 0 | 1 | 1.4025
1 | 0.0127 | 1 | 0.0127
2 | 0.0356 | 4 | 0.0712
2 | 0.02018 | 2 | 0.02018
1 | 0.0127 | 1 | 0.0127
1 | 0.0151 | 1 | 0.0151
1 | 0.0136 | 1 | 0.0136
| 0 | 3 | 0.03
| 0 | 1 | 0.058
| 0 | 1 | 0.122
1 | 0.0925 | 1 | 0.0925
| 0 | 1 | 0.11
2 | 0.7763 | 2 | 0.7763
| 0 | 1 | 0.60558
1 | 0.034 | 1 | 0.034
1 | 0.07434 | 1 | 0.07434
| 0 | 1 | 0.0334
| 0 | 2 | 0.01866
1 | 0.00933 | 1 | 0.00933
1 | 0.00933 | 1 | 0.00933
| 0 | 1 | 0.66414
1 | 2.31 | 1 | 2.31
| 0 | 1 | 3.301
1 | 0.782 | 1 | 0.782
| 0 | 1 | 1.061
1 | 0.15579
5.52172 12.60656

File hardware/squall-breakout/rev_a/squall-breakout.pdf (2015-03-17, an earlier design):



Top and Bottom Layers

Top Layer

Bottom Layer


Top Copper Layer


Bottom Copper Layer


Top Paste Layer with Silkscreen

Bottom Paste Layer with Silkscreen


Top and Bottom Layers 1:1 Scale


Top Layer 1:1 Scale


Bottom Copper Layer 1:1 Scale

### Sheet1

Qty Value | Device | Package | Parts
1 10nF | CAPACITOR | 0402_CAP | C1
7 0.1uF | CAPACITOR | 0402_CAP | C2, C3, C4, C5, C6, C7, C8
1 10uF | CAPACITOR | 0402_CAP | C9
1 22uF | CAP_POL0603 | CAP0603 | C10
3 SFH4056 | SFH4056 | SFH4056 | D1, D2, D3
1 DIODE | DIODE | 0402_DIODE | D4
2 SQUALL_HEADER | SQUALL_HEADER | SQUALL_HEADER | J1
1 | PINHD-2X2 | 2X02 | J2
1 308-100 | 308-100 | 308-100 | M1
1 ROHM-NPN-2SC5662 ROHM-NPN-2SC5662 VMT3 | Q1
1 30 | RESISTOR0402_RES 0402_RES | R1
1 33 | RESISTOR0402_RES 0402_RES | R2
1 1k | RESISTOR0402_RES 0402_RES | R3
2 10k | RESISTOR0402_RES 0402_RES | R4, R5
1 LPS331AP | LPS331AP | HCLGA-16/3MM | U1
1 MPU-9250 | MPU-9250 | QFN-24/3MM | U2
1 SI1147 | SI1147 | QFN-10/2MM | U3
1 SI7021 | SI7021 | DFN-6/3MM | U4

### Sheet1

Description | DIGIKEY
0402 Capacitor | 490-1312-1-ND
0402 Capacitor | 490-1318-1-ND
0402 Capacitor | 445-8919-1-ND
0603 Tantalum Capacitor | 511-1493-1-ND
LED IR EMITTER 850NM | 475-3042-1-ND
| 641-1277-1-ND
Header for a sensor board on top of the Squall BLE tag board. H11617CT-ND
PIN HEADER | 609-3201-ND
Pico Vibe
| 2SC5662T2LPCT-ND
Resistor | RHM30CECT-ND
Resistor | RHM33CECT-ND
Resistor | RHM1.0KCECT-ND
Resistor | RHM10.0KCDCT-ND
IC PRESSURE SENSOR PIEZO 16HCLGA | 497-12927-1-ND
GYRO/ACCEL/COMPASS/9-AXIS | 1428-1019-1-ND
SENSOR DGTL UV INDEX 10QFN | 336-2624-1-ND
IC TEMP SENSOR RH 2% DFN | 336-2542-1-ND

### Sheet1

PRECISION_MICRODRIVES

308-100

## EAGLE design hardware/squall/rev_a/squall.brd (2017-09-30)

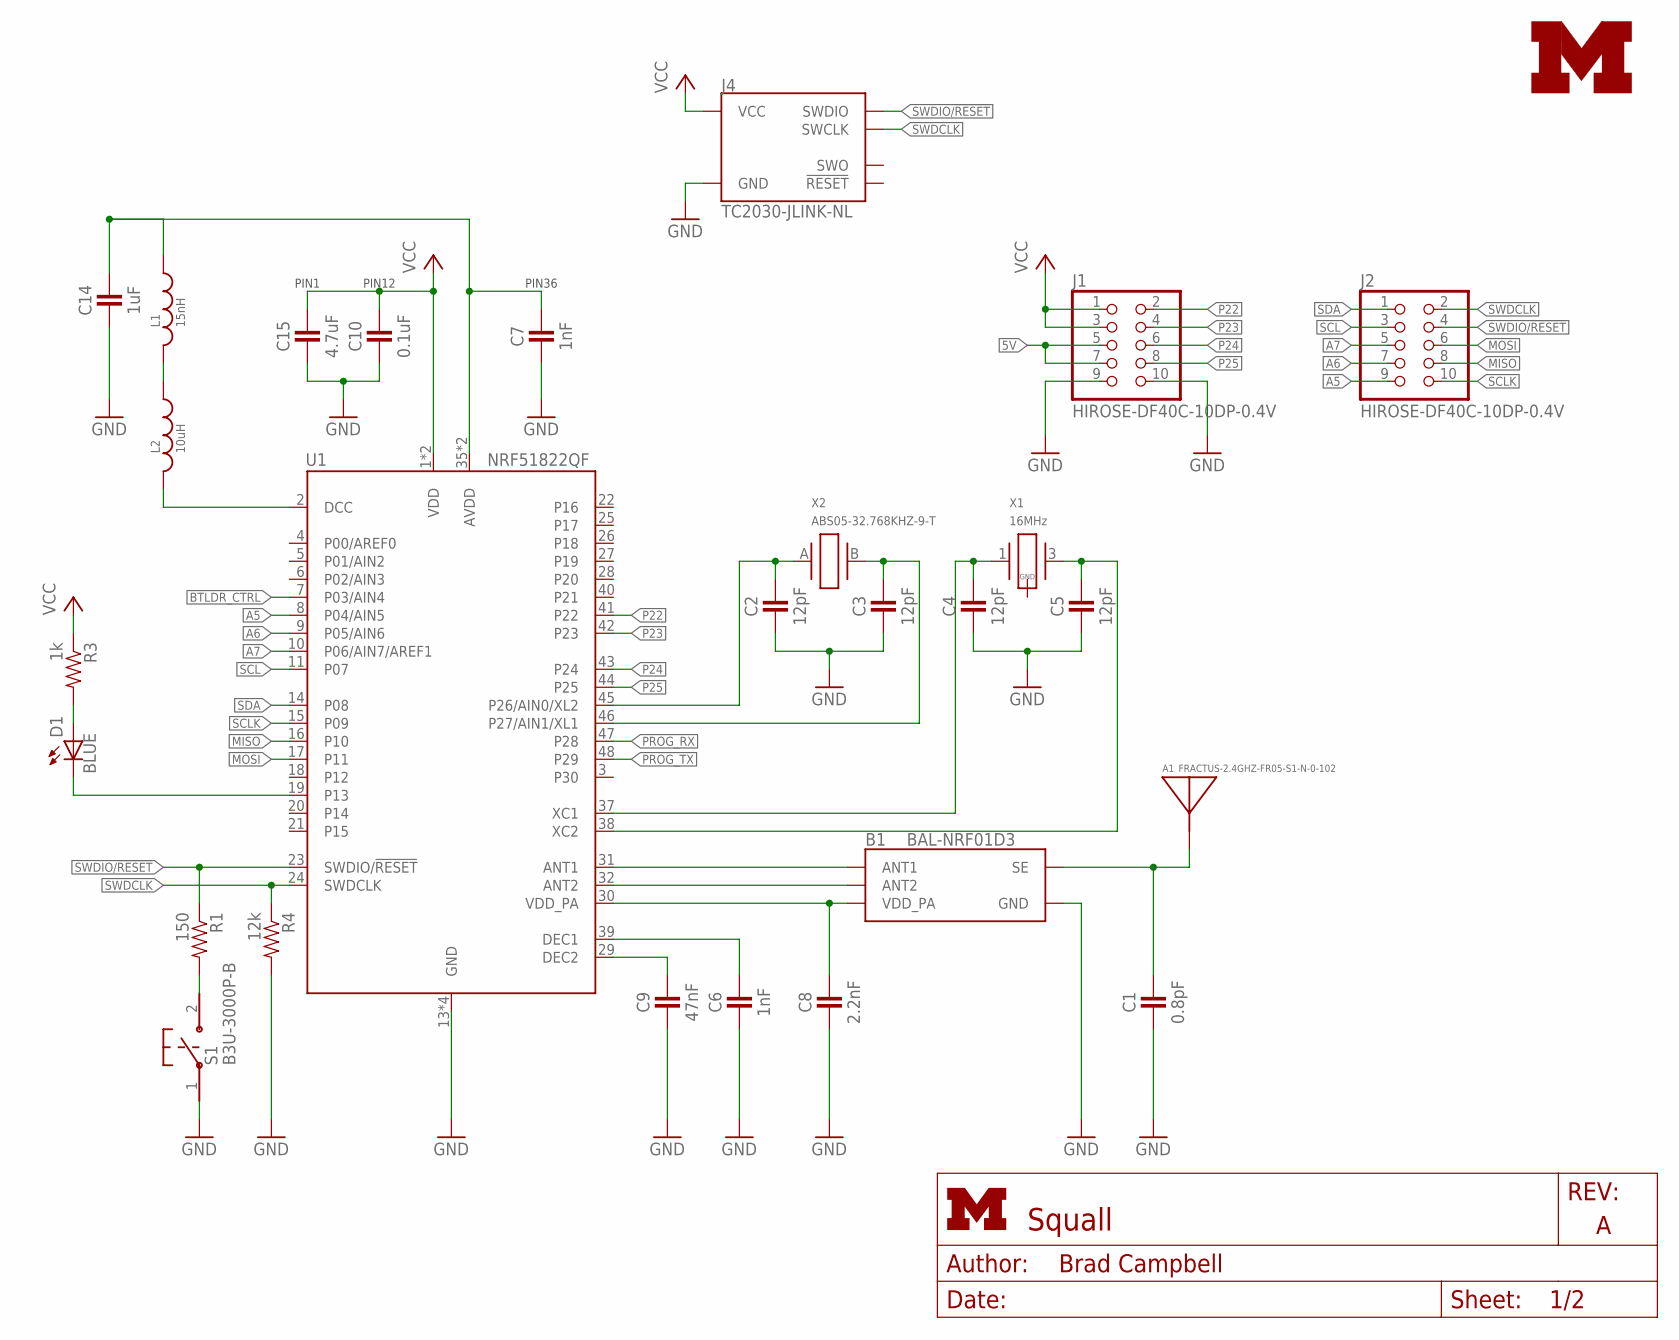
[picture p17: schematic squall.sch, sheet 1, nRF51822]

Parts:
A1: FRACTUS-2.4GHZ-FR05-S1-N-0-102; FRACTUS-ANTENNA-FR05-S1-N-0-102
B1: BAL-NRF01D3
C1: 0.8pF; 0402_CAP; MPN GRM1555C1HR80BA01D; DIGIKEY 490-6269-1-ND
C2, C3, C4, C5: 12pF; 0402_CAP; MPN GRM1555C1H120GA01D; DIGIKEY 490-6197-1-ND
C6, C7: 1nF; 0402_CAP; MPN GRM155R71H102KA01D; DIGIKEY 490-1303-1-ND
C8: 2.2nF; 0402_CAP; MPN GRM155R71E222KA01D; DIGIKEY 490-5419-1-ND
C9: 47nF; 0402_CAP; MPN C1005X7R1C473K050BC; DIGIKEY 445-1264-1-ND
C10: 0.1uF; 0402_CAP; MPN GRM155R61A104KA01D; DIGIKEY 490-1318-1-ND
C14: 1uF; 0402_CAP; MPN CL05B105KQ5NQNC; DIGIKEY 1276-1513-1-ND
C15: 4.7uF; 0402_CAP; MPN C1005X5R0J475K050BC; DIGIKEY 445-5947-1-ND
D1: BLUE; LED-0603
J1, J2: HIROSE-DF40C-10DP-0.4V; 2X5/SMD/0.4MM
J4: TC2030-JLINK-NL; TC2030-IDC-NL
L1: 15nH; 0402_CAP; MPN HK100515NJ-T; DIGIKEY 587-1521-1-ND
L2: 10uH; 0603_CAP; MPN LQM18FN100M00D; DIGIKEY 490-4025-1-ND
LOGO1: UMICH_SOLID_TINY; UMICH_SOLID_50MIL
R1: 150; 0402_RES; MPN MCR01MRTF1500; DIGIKEY RHM150CDCT-ND
R3: 1k; 0402_RES; MPN RC1005J102CS; DIGIKEY 1276-4376-1-ND
R4: 12k; 0402_RES; MPN RC1005F123CS; DIGIKEY 1276-4122-1-ND
S1: B3U-3000P-B
U1: NRF51822QF; QFN-48-6MM
X1: 16MHz; TXC-8Y; MPN 8Y-16.000MAAV-T; DIGIKEY 887-2003-1-ND
X2: ABS05-32.768KHZ-9-T; ABS05

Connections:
5V: J1.5, J1.7; also elsewhere on the board
A0: C2.1, U1.45 (P26/AIN0/XL2), X2.A (1)
A1: C3.1, U1.46 (P27/AIN1/XL1), X2.B (2)
A5: J2.9, U1.8 (P04/AIN5)
A6: J2.7, U1.9 (P05/AIN6)
A7: J2.5, U1.10 (P06/AIN7/AREF1)
AVDD: C7.1, C14.1, L1.1, U1.35 (AVDD), U1.36 (AVDD)
BTLDR_CTRL: U1.7 (P03/AIN4); also elsewhere on the board
DCC: L2.2, U1.2 (DCC)
GND: B1.GND, C1.2, C2.2, C3.2, C4.2, C5.2, C6.2, C7.2, C8.2, C9.2, C10.2, C14.2, C15.2, J1.9, J1.10, J4.5 (GND), R4.2, S1.1, U1.13 (GND), U1.33 (GND), U1.34 (GND), U1.GND; also elsewhere on the board
MISO: J2.8, U1.16 (P10)
MOSI: J2.6, U1.17 (P11)
unnamed: B1.ANT1, U1.31 (ANT1)
unnamed: B1.ANT2, U1.32 (ANT2)
unnamed: D1.C, U1.19 (P13)
unnamed: R1.2, S1.2
unnamed: A1.1, B1.SE, C1.1
unnamed: L1.2, L2.1
unnamed: C4.1, U1.37 (XC1), X1.1
unnamed: C5.1, U1.38 (XC2), X1.3 (2)
unnamed: C6.1, U1.39 (DEC1)
unnamed: C9.1, U1.29 (DEC2)
unnamed: D1.A, R3.2
P22: J1.2, U1.41 (P22)
P23: J1.4, U1.42 (P23)
P24: J1.6, U1.43 (P24)
P25: J1.8, U1.44 (P25)
PROG_RX: U1.47 (P28); also elsewhere on the board
PROG_TX: U1.48 (P29); also elsewhere on the board
SCL: J2.3, U1.11 (P07)
SCLK: J2.10, U1.15 (P09)
SDA: J2.1, U1.14 (P08)
SWDCLK: J2.2, J4.4 (SWCLK), R4.1, U1.24 (SWDCLK)
SWDIO/!RESET: J2.4, J4.2 (SWDIO), R1.1, U1.23 (SWDIO/!RESET)
VCC: C10.1, C15.1, J1.1, J1.3, J4.1 (VCC), R3.1, U1.1 (VDD), U1.12 (VDD); also elsewhere on the board
VDD_PA: B1.VCC (VDD_PA), C8.1, U1.30 (VDD_PA)

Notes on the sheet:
PIN1
PIN12
PIN36

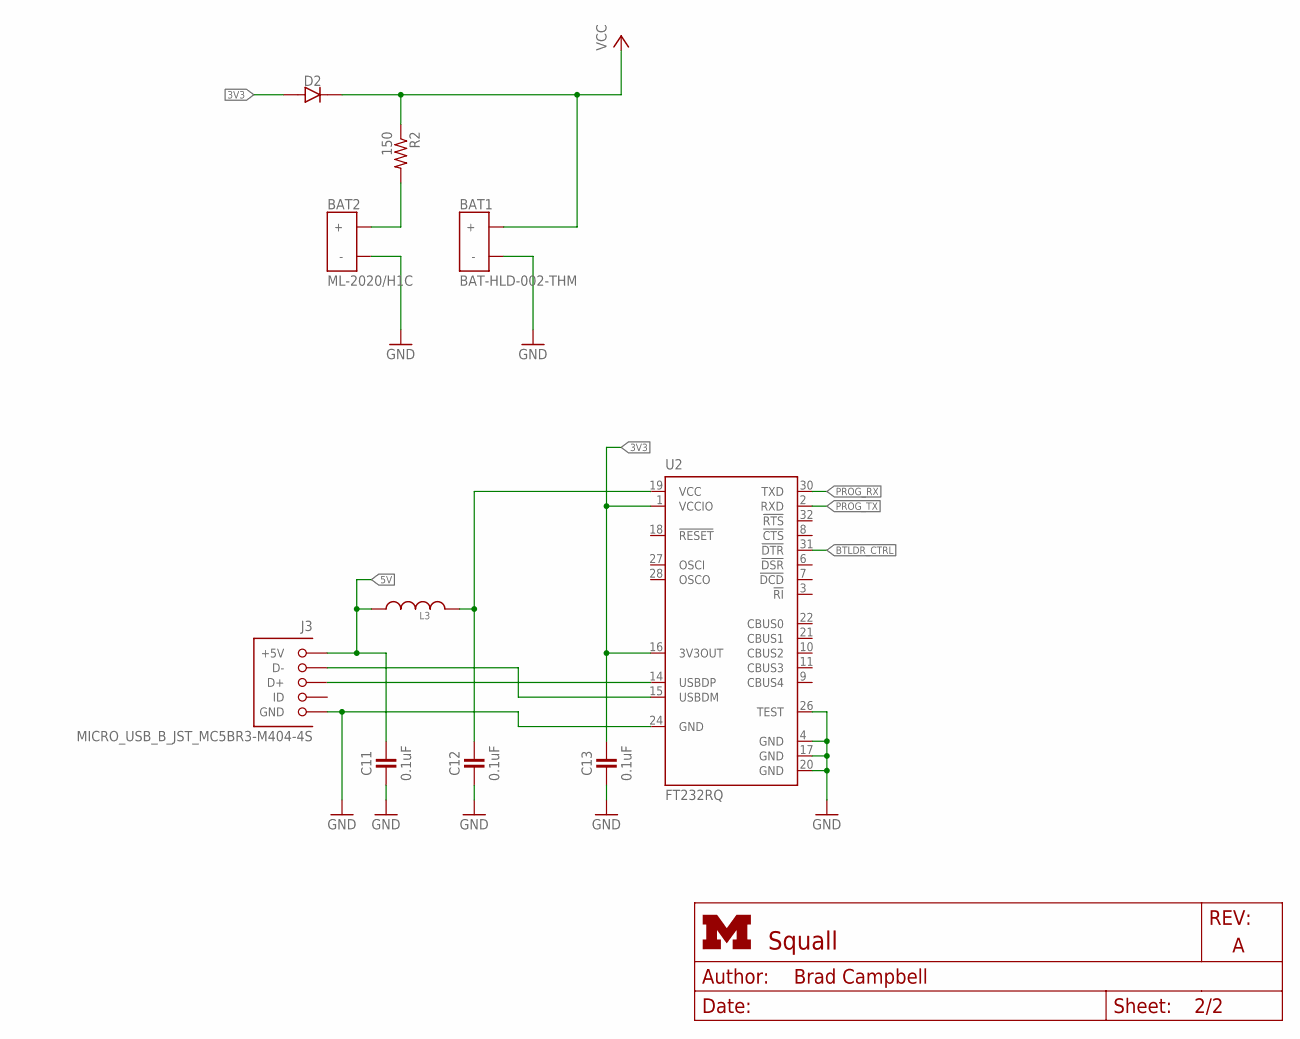
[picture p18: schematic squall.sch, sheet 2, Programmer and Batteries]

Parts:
BAT1: BAT-HLD-002-THM
BAT2: ML-2020/H1C
C11, C12, C13: 0.1uF; 0402_CAP; MPN GRM155R61A104KA01D; DIGIKEY 490-1318-1-ND
D2: DIODE; 0402_DIODE; MPN CDBQR0130L; DIGIKEY 641-1271-1-ND
J3: MICRO_USB_B_JST_MC5BR3-M404-4S; USB_MICRO_B-JST-MC5BR3-M404-4S-TB
L3: INDUCTOR0402; 0402_CAP; DIGIKEY 445-2979-1-ND
R2: 150; 0402_RES; MPN MCR01MRTF1500; DIGIKEY RHM150CDCT-ND
U2: FT232RQ; QFN32

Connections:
3V3: C13.1, D2.ANODE, U2.1 (VCCIO), U2.16 (3V3OUT)
5V: C11.1, J3.1 (+5V), L3.1; also elsewhere on the board
BTLDR_CTRL: U2.31 (!DTR); also elsewhere on the board
FTDI_VCC: C12.1, L3.2, U2.19 (VCC)
GND: BAT1.GND (-), BAT2.NEG (-), C11.2, C12.2, C13.2, J3.5 (GND), U2.4 (GND), U2.17 (GND), U2.20 (GND), U2.24 (GND), U2.26 (TEST); also elsewhere on the board
unnamed: BAT2.POS (+), R2.2
unnamed: J3.3 (D+), U2.14 (USBDP)
unnamed: J3.2 (D-), U2.15 (USBDM)
PROG_RX: U2.30 (TXD); also elsewhere on the board
PROG_TX: U2.2 (RXD); also elsewhere on the board
VCC: BAT1.POS1 (+), BAT1.POS2 (+), BAT1.POS3 (+), BAT1.POS4 (+), D2.CATHODE, R2.1; also elsewhere on the board

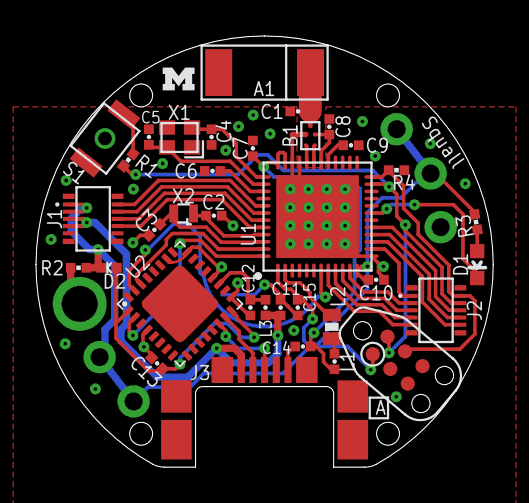
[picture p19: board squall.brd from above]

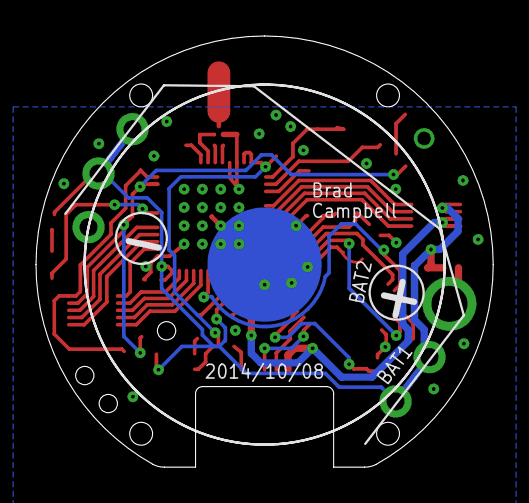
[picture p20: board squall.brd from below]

Board: 2 copper layers, 25.4 x 24.0 mm, 38 parts (2 on the bottom side), 41 nets.

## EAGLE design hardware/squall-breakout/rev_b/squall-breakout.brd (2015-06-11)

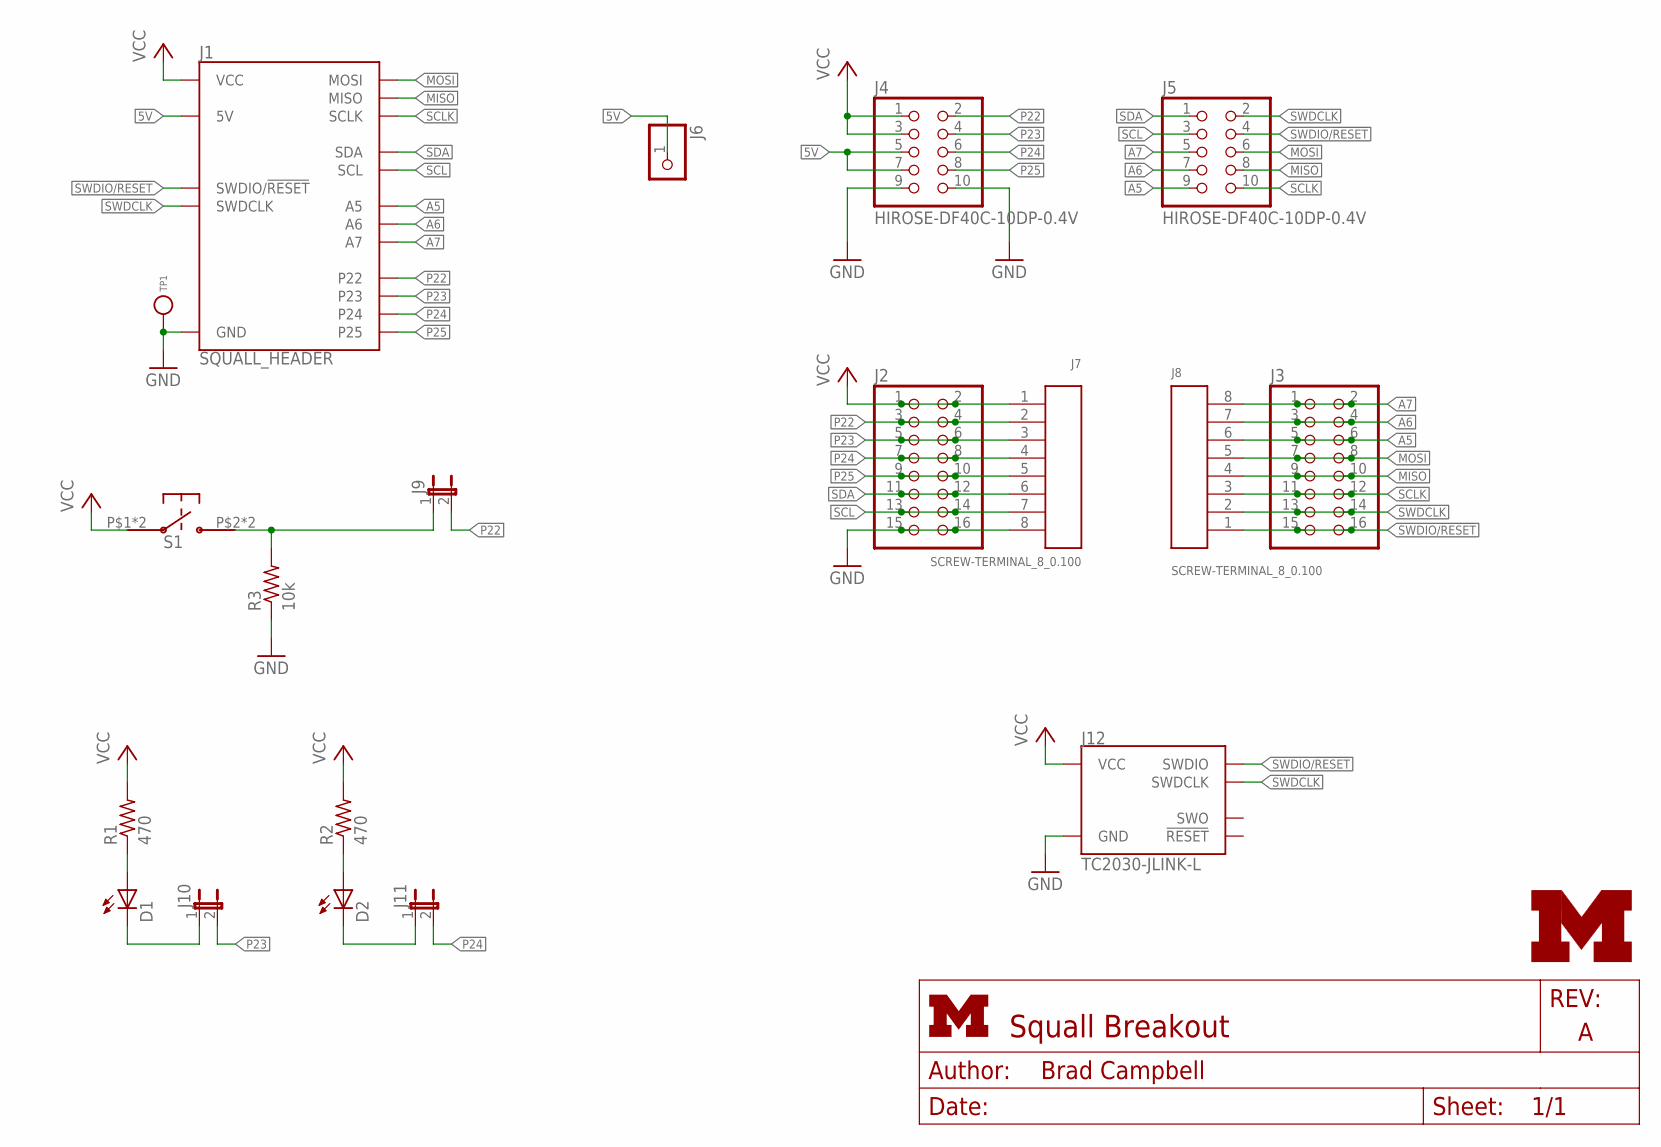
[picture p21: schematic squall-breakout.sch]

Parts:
D1, D2: LED0603; LED-0603
J1: SQUALL_HEADER
J2, J3: PINHD-2X8; 2X08
J4, J5: HIROSE-DF40C-10DP-0.4V; 2X5/SMD/0.4MM
J6: PINHD-1X1; 1X01
J7, J8: SCREW-TERMINAL_8_0.100; CONN_BLOCK_8
J9, J10, J11: JUMPER-2PTH; 1X02
J12: TC2030-JLINK-L; TC2030-IDC
LOGO1: UMICH_SOLID_TINY; UMICH_SOLID_50MIL
R1, R2: 470; R0603
R3: 10k; R0603
S1: EVQP2
TP1: TEST_POINT_0.112IN; TESTPOINT_0.112IN

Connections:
5V: J1.A5 (5V), J1.A7 (5V), J4.5, J4.7, J6.1
A5: J1.B9 (A5), J3.5, J3.6, J5.9, J8.6
A6: J1.B7 (A6), J3.3, J3.4, J5.7, J8.7
A7: J1.B5 (A7), J3.1, J3.2, J5.5, J8.8
GND: J1.A9 (GND), J1.A10 (GND), J2.15, J2.16, J4.9, J4.10, J7.8, J12.5 (GND), R3.1, TP1.1
MISO: J1.B8 (MISO), J3.9, J3.10, J5.8, J8.4
MOSI: J1.B6 (MOSI), J3.7, J3.8, J5.6, J8.5
unnamed: J9.1, R3.2, S1.P$2, S1.P$4
unnamed: D1.A, R1.1
unnamed: D1.C, J10.1
unnamed: D2.A, R2.1
unnamed: D2.C, J11.1
P22: J1.A2 (P22), J2.3, J2.4, J4.2, J7.2, J9.2
P23: J1.A4 (P23), J2.5, J2.6, J4.4, J7.3, J10.2
P24: J1.A6 (P24), J2.7, J2.8, J4.6, J7.4, J11.2
P25: J1.A8 (P25), J2.9, J2.10, J4.8, J7.5
SCL: J1.B3 (SCL), J2.13, J2.14, J5.3, J7.7
SCLK: J1.B10 (SCLK), J3.11, J3.12, J5.10, J8.3
SDA: J1.B1 (SDA), J2.11, J2.12, J5.1, J7.6
SWDCLK: J1.B2 (SWDCLK), J3.13, J3.14, J5.2, J8.2, J12.4 (SWDCLK)
SWDIO/!RESET: J1.B4 (SWDIO/!RESET), J3.15, J3.16, J5.4, J8.1, J12.2 (SWDIO)
VCC: J1.A1 (VCC), J1.A3 (VCC), J2.1, J2.2, J4.1, J4.3, J7.1, J12.1 (VCC), R1.2, R2.2, S1.P$1, S1.P$3

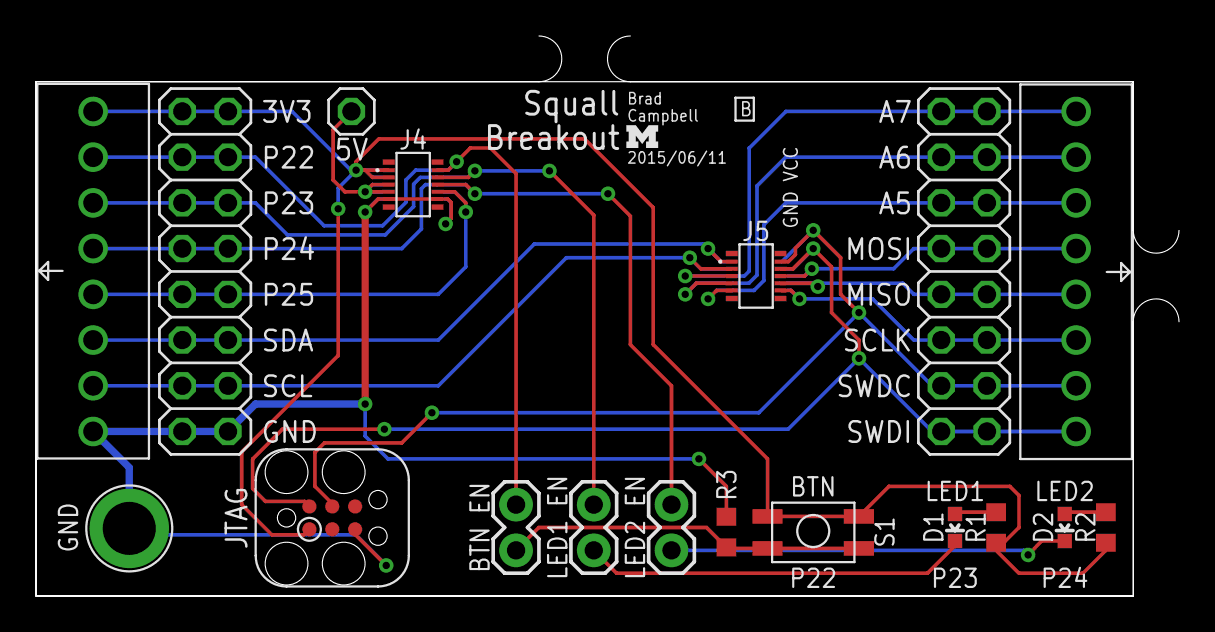
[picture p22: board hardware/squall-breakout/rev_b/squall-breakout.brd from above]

Board: 2 copper layers, 63.5 x 31.1 mm, 20 parts (0 on the bottom side), 22 nets.

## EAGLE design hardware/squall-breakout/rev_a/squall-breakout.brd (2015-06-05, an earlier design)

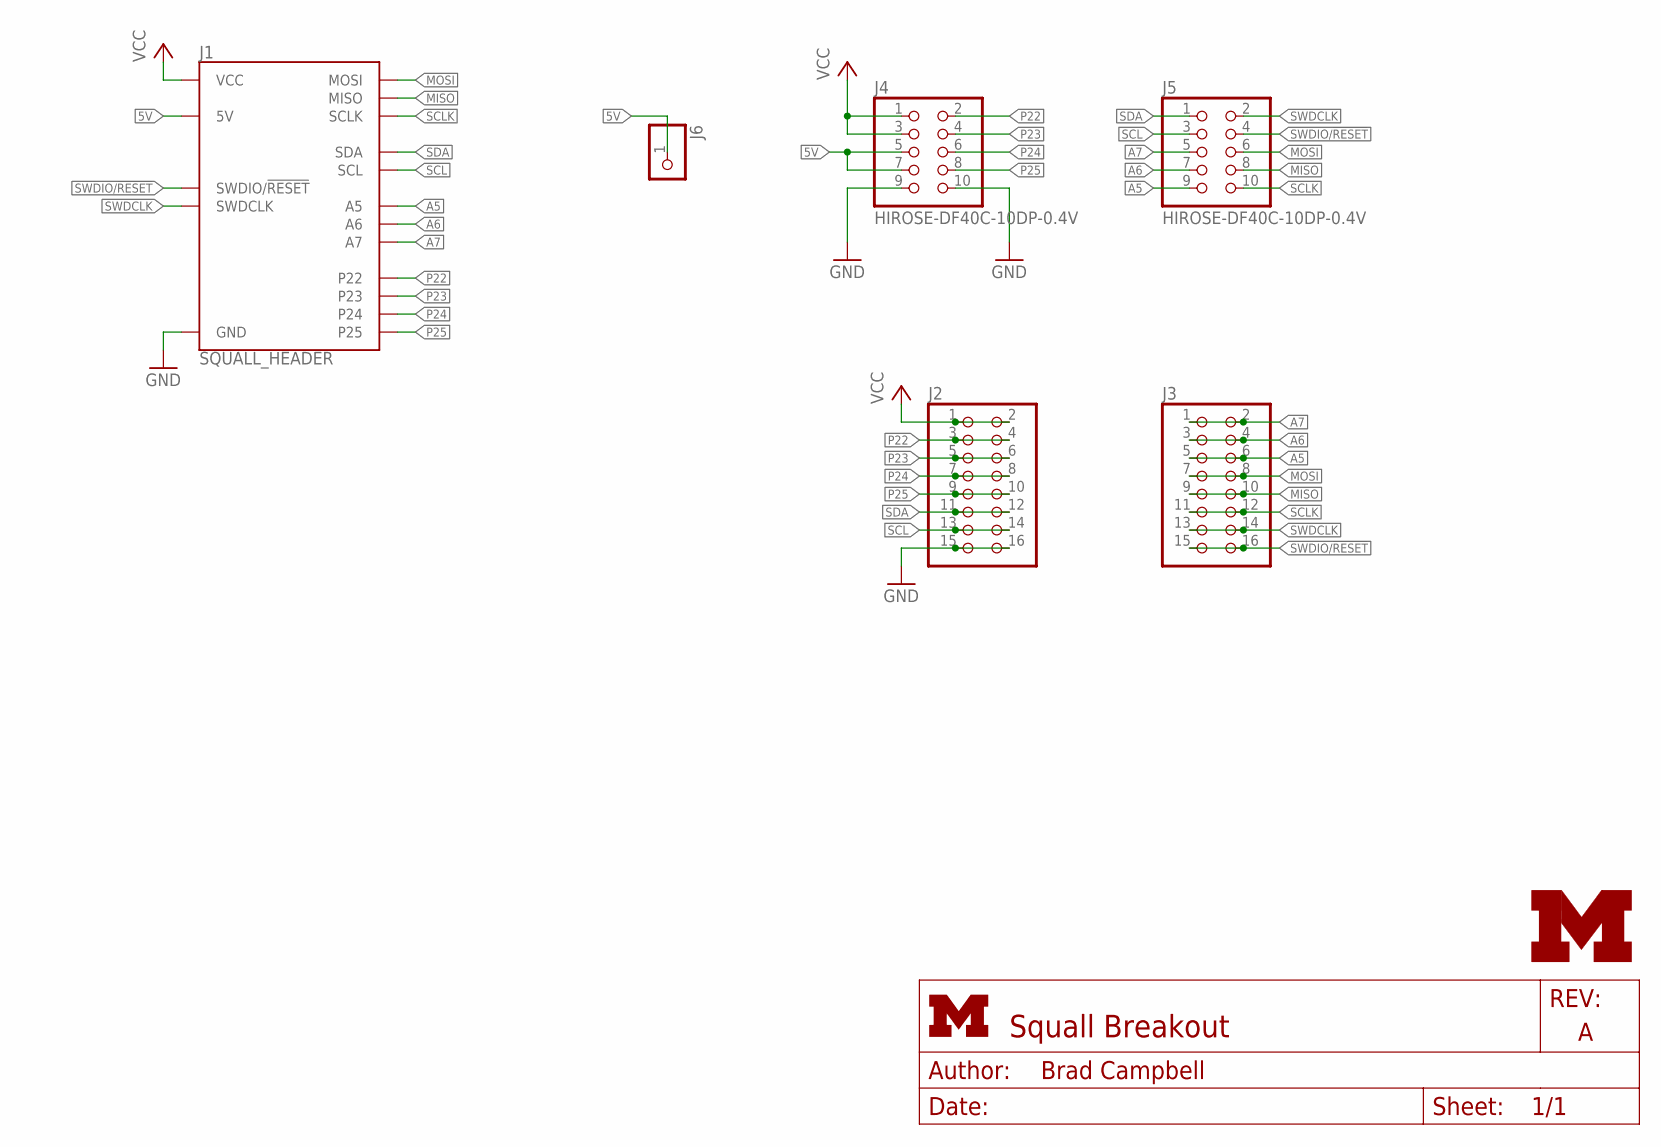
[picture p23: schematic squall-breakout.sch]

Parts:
J1: SQUALL_HEADER
J2, J3: PINHD-2X8; 2X08
J4, J5: HIROSE-DF40C-10DP-0.4V; 2X5/SMD/0.4MM
J6: PINHD-1X1; 1X01
LOGO1: UMICH_SOLID_TINY; UMICH_SOLID_50MIL

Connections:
5V: J1.A5 (5V), J1.A7 (5V), J4.5, J4.7, J6.1
A5: J1.B9 (A5), J3.5, J3.6, J5.9
A6: J1.B7 (A6), J3.3, J3.4, J5.7
A7: J1.B5 (A7), J3.1, J3.2, J5.5
GND: J1.A9 (GND), J1.A10 (GND), J2.15, J2.16, J4.9, J4.10
MISO: J1.B8 (MISO), J3.9, J3.10, J5.8
MOSI: J1.B6 (MOSI), J3.7, J3.8, J5.6
P22: J1.A2 (P22), J2.3, J2.4, J4.2
P23: J1.A4 (P23), J2.5, J2.6, J4.4
P24: J1.A6 (P24), J2.7, J2.8, J4.6
P25: J1.A8 (P25), J2.9, J2.10, J4.8
SCL: J1.B3 (SCL), J2.13, J2.14, J5.3
SCLK: J1.B10 (SCLK), J3.11, J3.12, J5.10
SDA: J1.B1 (SDA), J2.11, J2.12, J5.1
SWDCLK: J1.B2 (SWDCLK), J3.13, J3.14, J5.2
SWDIO/!RESET: J1.B4 (SWDIO/!RESET), J3.15, J3.16, J5.4
VCC: J1.A1 (VCC), J1.A3 (VCC), J2.1, J2.2, J4.1, J4.3

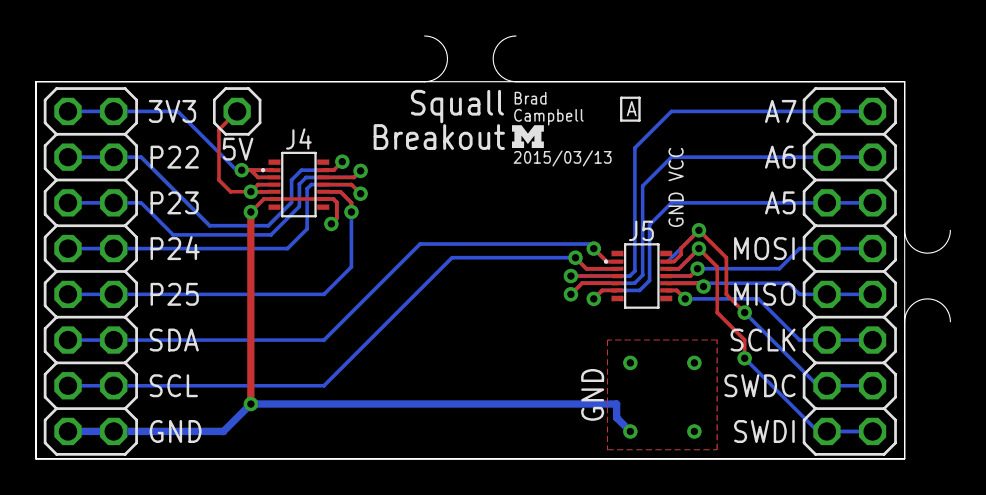
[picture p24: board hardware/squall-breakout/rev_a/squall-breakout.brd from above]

Board: 2 copper layers, 48.3 x 21.0 mm, 7 parts (0 on the bottom side), 17 nets.

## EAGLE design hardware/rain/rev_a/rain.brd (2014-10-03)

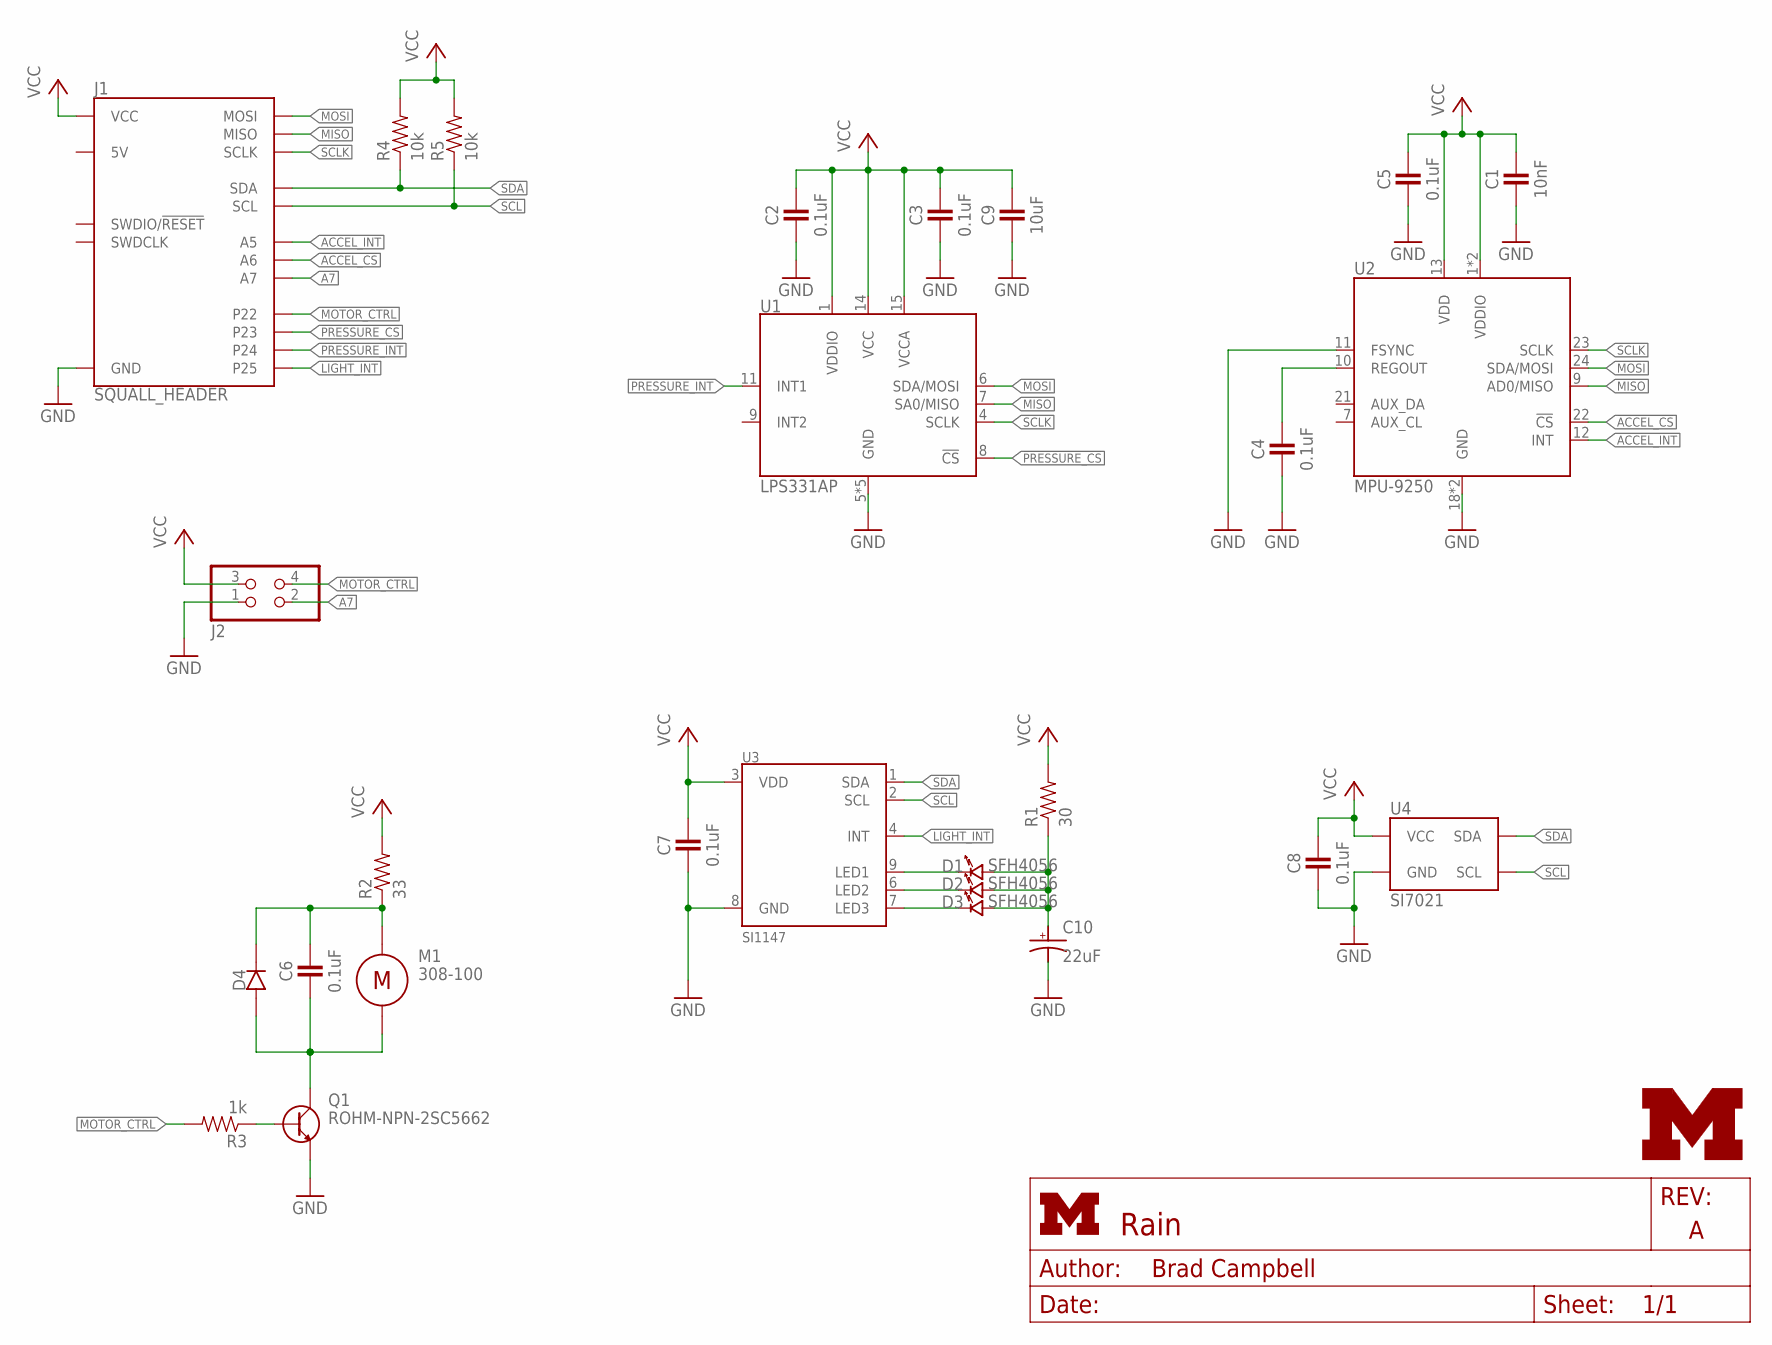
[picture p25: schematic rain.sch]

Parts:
C1: 10nF; 0402_CAP; DIGIKEY 490-1312-1-ND
C2, C3, C4, C5, C6, C7, C8: 0.1uF; 0402_CAP; DIGIKEY 490-1318-1-ND
C9: 10uF; 0402_CAP; DIGIKEY 445-8919-1-ND
C10: 22uF; CAP0603; DIGIKEY 511-1493-1-ND
D1, D2, D3: SFH4056
D4: DIODE; 0402_DIODE; DIGIKEY 641-1277-1-nd
J1: SQUALL_HEADER
J2: PINHD-2X2; 2X02; DIGIKEY 609-3201-ND
LOGO1: UMICH_SOLID_TINY; UMICH_SOLID_50MIL
M1: 308-100
Q1: ROHM-NPN-2SC5662; VMT3
R1: 30; 0402_RES; DIGIKEY RHM30CECT-ND
R2: 33; 0402_RES; DIGIKEY RHM33CECT-ND
R3: 1k; 0402_RES; DIGIKEY RHM1.0KCECT-ND
R4, R5: 10k; 0402_RES; DIGIKEY RHM10.0KCDCT-ND
U1: LPS331AP; HCLGA-16/3MM
U2: MPU-9250; QFN-24/3MM
U3: SI1147; QFN-10/2MM
U4: SI7021; DFN-6/3MM

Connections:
!ACCEL_CS: J1.B7 (A6), U2.22 (!CS)
!PRESSURE_CS: J1.A4 (P23), U1.8 (!CS)
A7: J1.B5 (A7), J2.2
ACCEL_INT: J1.B9 (A5), U2.12 (INT)
GND: C1.2, C2.2, C3.2, C4.2, C5.2, C7.2, C8.2, C9.2, C10.NEG (ANODE), J1.A9 (GND), J1.A10 (GND), J2.1, Q1.2 (EMITTER), U1.5 (GND), U1.10 (GND), U1.12 (GND), U1.13 (GND), U1.16 (GND), U2.11 (FSYNC), U2.18 (GND), U2.20 (GND), U3.8 (GND), U4.2 (GND)
LIGHT_INT: J1.A8 (P25), U3.4 (INT)
MISO: J1.B8 (MISO), U1.7 (SA0/MISO), U2.9 (AD0/MISO)
MOSI: J1.B6 (MOSI), U1.6 (SDA/MOSI), U2.24 (SDA/MOSI)
MOTOR_CTRL: J1.A2 (P22), J2.4, R3.2
unnamed: C6.1, D4.CATHODE, M1.POS, R2.1
unnamed: C6.2, D4.ANODE, M1.NEG, Q1.3 (COLLECTOR)
unnamed: C4.1, U2.10 (REGOUT)
unnamed: D1.CATHODE, U3.9 (LED1)
unnamed: Q1.1 (BASE), R3.1
unnamed: D2.CATHODE, U3.6 (LED2)
unnamed: D3.CATHODE, U3.7 (LED3)
unnamed: C10.POS (CATHODE), D1.ANODE, D2.ANODE, D3.ANODE, R1.1
PRESSURE_INT: J1.A6 (P24), U1.11 (INT1)
SCL: J1.B3 (SCL), R5.1, U3.2 (SCL), U4.6 (SCL)
SCLK: J1.B10 (SCLK), U1.4 (SCLK), U2.23 (SCLK)
SDA: J1.B1 (SDA), R4.1, U3.1 (SDA), U4.1 (SDA)
VCC: C1.1, C2.1, C3.1, C5.1, C7.1, C8.1, C9.1, J1.A1 (VCC), J1.A3 (VCC), J2.3, R1.2, R2.2, R4.2, R5.2, U1.1 (VDDIO), U1.14 (VCC), U1.15 (VCCA), U2.1 (VDDIO), U2.8 (VDDIO), U2.13 (VDD), U3.3 (VDD), U4.5 (VCC)

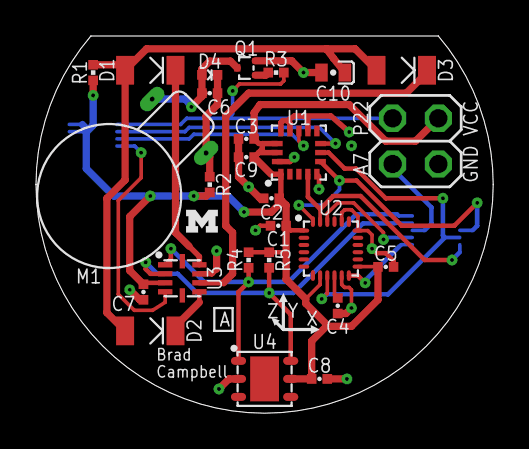
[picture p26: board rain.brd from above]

Board: 2 copper layers, 25.4 x 21.0 mm, 28 parts (0 on the bottom side), 22 nets.

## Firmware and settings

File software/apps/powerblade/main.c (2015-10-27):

/* Copyright (c) 2012 Nordic Semiconductor. All Rights Reserved.
 *
 * The information contained herein is property of Nordic Semiconductor ASA.
 * Terms and conditions of usage are described in detail in NORDIC
 * SEMICONDUCTOR STANDARD SOFTWARE LICENSE AGREEMENT.
 *
 * Licensees are granted free, non-transferable use of the information. NO
 * WARRANTY of ANY KIND is provided. This heading must NOT be removed from
 * the file.
 *
 */

/** @file
 *
 * @defgroup ble_sdk_uart_over_ble_main main.c
 * @{
 * @ingroup  ble_sdk_app_nus_eval
 * @brief    UART over BLE application main file.
 *
 * This file contains the source code for a sample application that uses the Nordic UART service.
 * This application uses the @ref srvlib_conn_params module.
 */

#include <stdint.h>
#include <string.h>
#include "nordic_common.h"
#include "nrf.h"
#include "nrf51_bitfields.h"
#include "nrf_gpio.h"
#include "ble_hci.h"
#include "ble_advdata.h"
#include "ble_conn_params.h"
#include "softdevice_handler.h"
#include "app_timer.h"
#include "app_gpiote.h"
#include "app_button.h"
#include "ble_nus.h"
#include "ble_gap.h"
#include "simple_uart.h"
#include "app_util_platform.h"
//#include "bsp.h"
#include "boards.h"

#include "eddystone.h"

void update_advertisement();

#define IS_SRVC_CHANGED_CHARACT_PRESENT 0                                           /**< Include or not the service_changed characteristic. if not enabled, the server's database cannot be changed for the lifetime of the device*/

#define WAKEUP_BUTTON_ID                0                                           /**< Button used to wake up the application. */

#define DEVICE_NAME                     "Nordic_UART"                               /**< Name of device. Will be included in the advertising data. */

#define APP_ADV_INTERVAL                MSEC_TO_UNITS(200, UNIT_0_625_MS)           /**< The advertising interval (in units of 0.625 ms. This value corresponds to 20 ms). */
//#define APP_ADV_INTERVAL                32                                          /**< The advertising interval (in units of 0.625 ms. This value corresponds to 20 ms). */
#define APP_ADV_TIMEOUT_IN_SECONDS      0                                           /**< The advertising timeout (in units of seconds). */

#define APP_TIMER_PRESCALER             0                                           /**< Value of the RTC1 PRESCALER register. */
#define APP_TIMER_MAX_TIMERS            (2 + 3)                 /**< Maximum number of simultaneously created timers. */
#define APP_TIMER_OP_QUEUE_SIZE         4                                           /**< Size of timer operation queues. */

#define APP_GPIOTE_MAX_USERS            1                                           /**< Maximum number of simultaneously gpiote users. */

#define MIN_CONN_INTERVAL               6                                          /**< Minimum acceptable connection interval (7.5 ms), Connection interval uses 1.25 ms units. */
#define MAX_CONN_INTERVAL               16                                          /**< Maximum acceptable connection interval (20 ms), Connection interval uses 1.25 ms units. */
#define SLAVE_LATENCY                   0                                           /**< slave latency. */
#define CONN_SUP_TIMEOUT                400                                         /**< Connection supervisory timeout (4 seconds), Supervision Timeout uses 10 ms units. */
#define FIRST_CONN_PARAMS_UPDATE_DELAY  APP_TIMER_TICKS(5000, APP_TIMER_PRESCALER)  /**< Time from initiating event (connect or start of notification) to first time sd_ble_gap_conn_param_update is called (5 seconds). */
#define NEXT_CONN_PARAMS_UPDATE_DELAY   APP_TIMER_TICKS(30000, APP_TIMER_PRESCALER) /**< Time between each call to sd_ble_gap_conn_param_update after the first call (30 seconds). */
#define MAX_CONN_PARAMS_UPDATE_COUNT    3                                           /**< Number of attempts before giving up the connection parameter negotiation. */

#define BUTTON_DETECTION_DELAY          APP_TIMER_TICKS(50, APP_TIMER_PRESCALER)    /**< Delay from a GPIOTE event until a button is reported as pushed (in number of timer ticks). */

#define SEC_PARAM_TIMEOUT               30                                          /**< Timeout for Pairing Request or Security Request (in seconds). */
#define SEC_PARAM_BOND                  1                                           /**< Perform bonding. */
#define SEC_PARAM_MITM                  0                                           /**< Man In The Middle protection not required. */
#define SEC_PARAM_IO_CAPABILITIES       BLE_GAP_IO_CAPS_NONE                        /**< No I/O capabilities. */
#define SEC_PARAM_OOB                   0                                           /**< Out Of Band data not available. */
#define SEC_PARAM_MIN_KEY_SIZE          7                                           /**< Minimum encryption key size. */
#define SEC_PARAM_MAX_KEY_SIZE          16                                          /**< Maximum encryption key size. */

#define START_STRING                    "Start...\n"                                /**< The string that will be sent over the UART when the application starts. */

#define DEAD_BEEF                       0xDEADBEEF                                  /**< Value used as error code on stack dump, can be used to identify stack location on stack unwind. */

static ble_gap_sec_params_t             m_sec_params;                               /**< Security requirements for this application. */
static uint16_t                         m_conn_handle = BLE_CONN_HANDLE_INVALID;    /**< Handle of the current connection. */
static ble_nus_t                        m_nus;                                      /**< Structure to identify the Nordic UART Service. */

// timer to tell the uart to turn back on
app_timer_id_t on_timer;

// Advertising data specifications
#define APP_COMPANY_IDENTIFIER 0x4908
#define ADV_DATA_LENGTH 0x14  // 0x17 Stolen from another example. Is this the maximum?
static uint8_t adv_index = 0;
static uint8_t advertising_data[ADV_DATA_LENGTH];
static uint8_t num_connections = 0;

static ble_uuid_t PHYSWEB_SERVICE_UUID[] = {{PHYSWEB_SERVICE_ID, BLE_UUID_TYPE_BLE}};
static ble_advdata_uuid_list_t PHYSWEB_SERVICE_LIST = {1, PHYSWEB_SERVICE_UUID};
#define PHYSWEB_URL                     "goo.gl/jEKPu9"
app_timer_id_t eddystone_on_timer;
app_timer_id_t eddystone_off_timer;

// BLE Address
uint8_t MAC_ADDR[6] = {0x00, 0x00, 0x70, 0xe5, 0x98, 0xc0};
#define ADDRESS_FLASH_LOCATION 0x0001fff8

// GPIO Output pin to MSP430
#define OUTPUT_PIN 13

void app_error_handler(uint32_t error_code, uint32_t line_num, const uint8_t * p_file_name) {
    nrf_gpio_cfg_output(LED_0);
    nrf_gpio_pin_clear(LED_0);
    while(1);
}

/**@brief       Assert macro callback function.
 *
 * @details     This function will be called in case of an assert in the SoftDevice.
 *
 * @warning     This handler is an example only and does not fit a final product. You need to
 *              analyze how your product is supposed to react in case of Assert.
 * @warning     On assert from the SoftDevice, the system can only recover on reset.
 *
 * @param[in]   line_num   Line number of the failing ASSERT call.
 * @param[in]   file_name  File name of the failing ASSERT call.
 */
void assert_nrf_callback(uint16_t line_num, const uint8_t * p_file_name)
{
    app_error_handler(DEAD_BEEF, line_num, p_file_name);
}


/**@brief   Function for the GAP initialization.
 *
 * @details This function will setup all the necessary GAP (Generic Access Profile)
 *          parameters of the device. It also sets the permissions and appearance.
 */
static void gap_params_init(void)
{
    uint32_t                err_code;
    ble_gap_conn_params_t   gap_conn_params;
    ble_gap_conn_sec_mode_t sec_mode;

    sd_ble_gap_tx_power_set(4);

    BLE_GAP_CONN_SEC_MODE_SET_OPEN(&sec_mode);

    err_code = sd_ble_gap_device_name_set(&sec_mode,
                                          (const uint8_t *)"PowerBlade",
                                          10);
    APP_ERROR_CHECK(err_code);

    memset(&gap_conn_params, 0, sizeof(gap_conn_params));

    gap_conn_params.min_conn_interval = MIN_CONN_INTERVAL;
    gap_conn_params.max_conn_interval = MAX_CONN_INTERVAL;
    gap_conn_params.slave_latency     = SLAVE_LATENCY;
    gap_conn_params.conn_sup_timeout  = CONN_SUP_TIMEOUT;

    err_code = sd_ble_gap_ppcp_set(&gap_conn_params);
    APP_ERROR_CHECK(err_code);
}

/**@brief   Function for the Advertising functionality initialization.
 *
 * @details Encodes the required advertising data and passes it to the stack.
 *          Also builds a structure to be passed to the stack when starting advertising.
 */
static void advertising_init(void)
{

    uint32_t                  err_code;
    ble_advdata_t advdata;
    ble_advdata_manuf_data_t manuf_specific_data;
    //ble_advdata_t scanrsp;
    //uint8_t       flags = BLE_GAP_ADV_FLAGS_LE_ONLY_LIMITED_DISC_MODE;
    uint8_t flags = BLE_GAP_ADV_FLAG_BR_EDR_NOT_SUPPORTED;

    // Build and set advertising data.
    memset(&advdata, 0, sizeof(advdata));

    manuf_specific_data.company_identifier = APP_COMPANY_IDENTIFIER;
    manuf_specific_data.data.p_data = advertising_data;
    manuf_specific_data.data.size   = ADV_DATA_LENGTH;

    //advdata.name_type               = BLE_ADVDATA_FULL_NAME;
    //advdata.name_type               = BLE_ADVDATA_SHORT_NAME;
    //advdata.short_name_len          = 5;
    advdata.name_type               = BLE_ADVDATA_NO_NAME;
    advdata.include_appearance      = false;
    advdata.flags.size              = sizeof(flags);
    advdata.flags.p_data            = &flags;
    advdata.p_manuf_specific_data   = &manuf_specific_data;

    err_code = ble_advdata_set(&advdata, NULL);
    APP_ERROR_CHECK(err_code);

    // No scan response data for now
    //ble_uuid_t adv_uuids[] = {{BLE_UUID_NUS_SERVICE, m_nus.uuid_type}};
    //memset(&scanrsp, 0, sizeof(scanrsp));
    //scanrsp.uuids_complete.uuid_cnt = sizeof(adv_uuids) / sizeof(adv_uuids[0]);
    //scanrsp.uuids_complete.p_uuids  = adv_uuids;
    //err_code = ble_advdata_set(&advdata, &scanrsp);
    //APP_ERROR_CHECK(err_code);
}


/**@brief    Function for handling the data from the Nordic UART Service.
 *
 * @details  This function will process the data received from the Nordic UART BLE Service and send
 *           it to the UART module.
 */
/**@snippet [Handling the data received over BLE] */
void nus_data_handler(ble_nus_t * p_nus, uint8_t * p_data, uint16_t length)
{
    ble_nus_send_string(p_nus, p_data, length);

    //for (int i = 0; i < length; i++)
    //{
        //simple_uart_put(p_data[i]);
    //}
    //simple_uart_put('\n');
}
/**@snippet [Handling the data received over BLE] */


/**@brief Function for initializing services that will be used by the application.
 */
static void services_init(void)
{
    uint32_t         err_code;
    ble_nus_init_t   nus_init;

    memset(&nus_init, 0, sizeof(nus_init));

    nus_init.data_handler = nus_data_handler;

    err_code = ble_nus_init(&m_nus, &nus_init);
    APP_ERROR_CHECK(err_code);
}


/**@brief Function for initializing security parameters.
 */
static void sec_params_init(void)
{
    m_sec_params.timeout      = SEC_PARAM_TIMEOUT;
    m_sec_params.bond         = SEC_PARAM_BOND;
    m_sec_params.mitm         = SEC_PARAM_MITM;
    m_sec_params.io_caps      = SEC_PARAM_IO_CAPABILITIES;
    m_sec_params.oob          = SEC_PARAM_OOB;
    m_sec_params.min_key_size = SEC_PARAM_MIN_KEY_SIZE;
    m_sec_params.max_key_size = SEC_PARAM_MAX_KEY_SIZE;
}


/**@brief       Function for handling an event from the Connection Parameters Module.
 *
 * @details     This function will be called for all events in the Connection Parameters Module
 *              which are passed to the application.
 *
 * @note        All this function does is to disconnect. This could have been done by simply setting
 *              the disconnect_on_fail config parameter, but instead we use the event handler
 *              mechanism to demonstrate its use.
 *
 * @param[in]   p_evt   Event received from the Connection Parameters Module.
 */
static void on_conn_params_evt(ble_conn_params_evt_t * p_evt)
{
    uint32_t err_code;

    if(p_evt->evt_type == BLE_CONN_PARAMS_EVT_FAILED)
    {
        err_code = sd_ble_gap_disconnect(m_conn_handle, BLE_HCI_CONN_INTERVAL_UNACCEPTABLE);
        APP_ERROR_CHECK(err_code);
    }
}


/**@brief       Function for handling errors from the Connection Parameters module.
 *
 * @param[in]   nrf_error   Error code containing information about what went wrong.
 */
static void conn_params_error_handler(uint32_t nrf_error)
{
    APP_ERROR_HANDLER(nrf_error);
}


/**@brief Function for initializing the Connection Parameters module.
 */
static void conn_params_init(void)
{
    uint32_t               err_code;
    ble_conn_params_init_t cp_init;

    memset(&cp_init, 0, sizeof(cp_init));

    cp_init.p_conn_params                  = NULL;
    cp_init.first_conn_params_update_delay = FIRST_CONN_PARAMS_UPDATE_DELAY;
    cp_init.next_conn_params_update_delay  = NEXT_CONN_PARAMS_UPDATE_DELAY;
    cp_init.max_conn_params_update_count   = MAX_CONN_PARAMS_UPDATE_COUNT;
    cp_init.start_on_notify_cccd_handle    = BLE_GATT_HANDLE_INVALID;
    cp_init.disconnect_on_fail             = false;
    cp_init.evt_handler                    = on_conn_params_evt;
    cp_init.error_handler                  = conn_params_error_handler;

    err_code = ble_conn_params_init(&cp_init);
    APP_ERROR_CHECK(err_code);
}


/**@brief Function for starting advertising.
 */
static void advertising_start(void)
{
    uint32_t             err_code;
    ble_gap_adv_params_t adv_params;

    // Start advertising
    memset(&adv_params, 0, sizeof(adv_params));

    adv_params.type        = BLE_GAP_ADV_TYPE_ADV_IND;
    adv_params.timeout     = APP_ADV_TIMEOUT_IN_SECONDS;
    adv_params.p_peer_addr = NULL;
    adv_params.fp          = BLE_GAP_ADV_FP_ANY;
    adv_params.interval    = APP_ADV_INTERVAL;

    err_code = sd_ble_gap_adv_start(&adv_params);
    APP_ERROR_CHECK(err_code);

    //err_code = bsp_indication_set(BSP_INDICATE_ADVERTISING);
    //APP_ERROR_CHECK(err_code);
}


/**@brief       Function for the Application's S110 SoftDevice event handler.
 *
 * @param[in]   p_ble_evt   S110 SoftDevice event.
 */
static void on_ble_evt(ble_evt_t * p_ble_evt)
{
    uint32_t                         err_code;
    static ble_gap_evt_auth_status_t m_auth_status;
    ble_gap_enc_info_t *             p_enc_info;

    switch (p_ble_evt->header.evt_id)
    {
        case BLE_GAP_EVT_CONNECTED:
            //err_code = bsp_indication_set(BSP_INDICATE_CONNECTED);
            //APP_ERROR_CHECK(err_code);
            //nrf_gpio_pin_set(OUTPUT_PIN);
            num_connections++;
            m_conn_handle = p_ble_evt->evt.gap_evt.conn_handle;

            break;

        case BLE_GAP_EVT_DISCONNECTED:
            //err_code = bsp_indication_set(BSP_INDICATE_IDLE);
            //APP_ERROR_CHECK(err_code);
            m_conn_handle = BLE_CONN_HANDLE_INVALID;

            advertising_start();

            break;

        case BLE_GAP_EVT_SEC_PARAMS_REQUEST:
            err_code = sd_ble_gap_sec_params_reply(m_conn_handle,
                                                   BLE_GAP_SEC_STATUS_SUCCESS,
                                                   &m_sec_params);
            APP_ERROR_CHECK(err_code);
            break;

        case BLE_GATTS_EVT_SYS_ATTR_MISSING:
            err_code = sd_ble_gatts_sys_attr_set(m_conn_handle, NULL, 0);
            APP_ERROR_CHECK(err_code);
            break;

        case BLE_GAP_EVT_AUTH_STATUS:
            m_auth_status = p_ble_evt->evt.gap_evt.params.auth_status;
            break;

        case BLE_GAP_EVT_SEC_INFO_REQUEST:
            p_enc_info = &m_auth_status.periph_keys.enc_info;
            if (p_enc_info->div == p_ble_evt->evt.gap_evt.params.sec_info_request.div)
            {
                err_code = sd_ble_gap_sec_info_reply(m_conn_handle, p_enc_info, NULL);
                APP_ERROR_CHECK(err_code);
            }
            else
            {
                // No keys found for this device
                err_code = sd_ble_gap_sec_info_reply(m_conn_handle, NULL, NULL);
                APP_ERROR_CHECK(err_code);
            }
            break;

        case BLE_GAP_EVT_TIMEOUT:
            if (p_ble_evt->evt.gap_evt.params.timeout.src == BLE_GAP_TIMEOUT_SRC_ADVERTISEMENT)
            {
                //err_code = bsp_indication_set(BSP_INDICATE_IDLE);
                //APP_ERROR_CHECK(err_code);
                // Configure buttons with sense level low as wakeup source.
                //err_code = bsp_buttons_enable(1 << WAKEUP_BUTTON_ID);
                //APP_ERROR_CHECK(err_code);
                // Go to system-off mode (this function will not return; wakeup will cause a reset)
                //err_code = sd_power_system_off();
                //APP_ERROR_CHECK(err_code);
            }
            break;

        default:
            // No implementation needed.
            break;
    }
}


/**@brief       Function for dispatching a S110 SoftDevice event to all modules with a S110
 *              SoftDevice event handler.
 *
 * @details     This function is called from the S110 SoftDevice event interrupt handler after a
 *              S110 SoftDevice event has been received.
 *
 * @param[in]   p_ble_evt   S110 SoftDevice event.
 */
static void ble_evt_dispatch(ble_evt_t * p_ble_evt)
{
    ble_conn_params_on_ble_evt(p_ble_evt);
    ble_nus_on_ble_evt(&m_nus, p_ble_evt);
    on_ble_evt(p_ble_evt);
}


/**@brief   Function for the S110 SoftDevice initialization.
 *
 * @details This function initializes the S110 SoftDevice and the BLE event interrupt.
 */
static void ble_stack_init(void)
{
    uint32_t err_code;

    // Initialize SoftDevice.
    //SOFTDEVICE_HANDLER_INIT(NRF_CLOCK_LFCLKSRC_XTAL_20_PPM, false);
    SOFTDEVICE_HANDLER_INIT(NRF_CLOCK_LFCLKSRC_RC_250_PPM_8000MS_CALIBRATION, false);

    // Enable BLE stack
    ble_enable_params_t ble_enable_params;
    memset(&ble_enable_params, 0, sizeof(ble_enable_params));
    ble_enable_params.gatts_enable_params.service_changed = IS_SRVC_CHANGED_CHARACT_PRESENT;
    err_code = sd_ble_enable(&ble_enable_params);
    APP_ERROR_CHECK(err_code);

    // Subscribe for BLE events.
    err_code = softdevice_ble_evt_handler_set(ble_evt_dispatch);
    APP_ERROR_CHECK(err_code);

    // Set the MAC address of the device
    uint8_t _ble_address[6];
    memcpy(_ble_address, (uint8_t*)ADDRESS_FLASH_LOCATION, 6);
    if (_ble_address[1] == 0xFF && _ble_address[0] == 0xFF) {
        // No user-defined address stored in flash, user manufacturer address
        //  with Michigan OUI
        ble_gap_addr_t gap_addr;

        // Get the full manufacturer address
        sd_ble_gap_address_get(&gap_addr);

        // Set the new BLE address with the Michigan OUI
        gap_addr.addr_type = BLE_GAP_ADDR_TYPE_PUBLIC;
        memcpy(gap_addr.addr+2, MAC_ADDR+2, sizeof(gap_addr.addr)-2);
        err_code = sd_ble_gap_address_set(BLE_GAP_ADDR_CYCLE_MODE_NONE,
                &gap_addr);
        APP_ERROR_CHECK(err_code);
    } else {
        // Use user-defined address from flash
        ble_gap_addr_t gap_addr;

        // Set the new BLE address with the user-defined address
        gap_addr.addr_type = BLE_GAP_ADDR_TYPE_PUBLIC;
        memcpy(gap_addr.addr, _ble_address, 6);
        err_code = sd_ble_gap_address_set(BLE_GAP_ADDR_CYCLE_MODE_NONE,
                &gap_addr);
        APP_ERROR_CHECK(err_code);
    }
}


/**@brief  Function for placing the application in low power state while waiting for events.
 */
static void power_manage(void)
{
    uint32_t err_code = sd_app_evt_wait();
    APP_ERROR_CHECK(err_code);
}


/**@brief  Function for initializing the UART module.
 */
static void uart_init(void)
{
    /**@snippet [UART Initialization] */
    simple_uart_config(RTS_PIN_NUMBER, TX_PIN_NUMBER, CTS_PIN_NUMBER, RX_PIN_NUMBER, HWFC);

    NRF_UART0->INTENSET = UART_INTENSET_RXDRDY_Enabled << UART_INTENSET_RXDRDY_Pos;

    NVIC_SetPriority(UART0_IRQn, APP_IRQ_PRIORITY_LOW);
    NVIC_EnableIRQ(UART0_IRQn);
    /**@snippet [UART Initialization] */
}

static void uart_disable(void)
{
    NRF_UART0->TASKS_STOPTX = 1;
    NRF_UART0->TASKS_STOPRX = 1;
    NRF_UART0->ENABLE = (UART_ENABLE_ENABLE_Disabled << UART_ENABLE_ENABLE_Pos);
}
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
int main(void)
{
    // Started. GPIO low
    //nrf_gpio_cfg_output(LED_0);
    //nrf_gpio_pin_set(LED_0);
    //nrf_gpio_pin_clear(LED_0);

    uint8_t start_string[] = START_STRING;
    uint32_t err_code;
    // Initialize
    APP_TIMER_INIT(APP_TIMER_PRESCALER, APP_TIMER_MAX_TIMERS, APP_TIMER_OP_QUEUE_SIZE, false);
    APP_GPIOTE_INIT(APP_GPIOTE_MAX_USERS);
    ble_stack_init();

    app_timer_create(&on_timer, APP_TIMER_MODE_SINGLE_SHOT, on_timer_expired);
    app_timer_create(&eddystone_on_timer, APP_TIMER_MODE_SINGLE_SHOT, eddystone_advertisement);
    app_timer_create(&eddystone_off_timer, APP_TIMER_MODE_SINGLE_SHOT, update_advertisement);

    //TODO: Pull in simple_uart code to change baudrate
    uart_init();
    on_timer_expired();

    // init adv data to 0s
    memset(advertising_data, 0, ADV_DATA_LENGTH);

    gap_params_init();
    services_init();
    //advertising_init();
    conn_params_init();
    sec_params_init();

    update_advertisement();
    //eddystone_advertisement();

    advertising_start();

    // Ready to receive UART data
    num_connections = 0;
    //nrf_gpio_pin_set(OUTPUT_PIN);

    // Enter main loop
    for (;;)
    {
        power_manage();
    }
}

/**
 * @}
 */

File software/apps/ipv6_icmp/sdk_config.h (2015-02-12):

/* Copyright (c) 2013 Nordic Semiconductor. All Rights Reserved.
 *
 * The information contained herein is property of Nordic Semiconductor ASA.
 * Terms and conditions of usage are described in detail in NORDIC
 * SEMICONDUCTOR STANDARD SOFTWARE LICENSE AGREEMENT.
 *
 * Licensees are granted free, non-transferable use of the information. NO
 * WARRANTY of ANY KIND is provided. This heading must NOT be removed from
 * the file.
 *
 */
#ifndef SDK_CONFIG_H__
#define SDK_CONFIG_H__

/**
 * @defgroup sdk_config SDK Configuration
 * @{
 * @ingroup sdk_common
 * @{
 * @details All parameters that allow configuring/tuning the SDK based on application/ use case
 *          are defined here.
 */


/**
 * @defgroup mem_manager_config Memory Manager Configuration
 * @{
 * @addtogroup sdk_config
 * @{
 * @details This section defines configuration of memory manager module.
 */

/**
 * @brief Maximum memory blocks identified as 'small' blocks.
 *
 * @details Maximum memory blocks identified as 'small' blocks.
 *          Minimum value : 0 (Setting to 0 disables all 'small' blocks)
 *          Maximum value : 255
 *          Dependencies  : None.
 */
#define  MEMORY_MANAGER_SMALL_BLOCK_COUNT                  4

/**
 * @brief Size of each memory blocks identified as 'small' block.
 *
 * @details Size of each memory blocks identified as 'small' block.
 *          Memory block are recommended to be word-sized.
 *          Minimum value : 32
 *          Maximum value : A value less than the next pool size. If only small pool is used, this
 *                          can be any value based on availability of RAM.
 *          Dependencies  : MEMORY_MANAGER_SMALL_BLOCK_COUNT is non-zero.
 */
#define  MEMORY_MANAGER_SMALL_BLOCK_SIZE                   128

/**
 * @brief Maximum memory blocks identified as 'medium' blocks.
 *
 * @details Maximum memory blocks identified as 'medium' blocks.
 *          Minimum value : 0 (Setting to 0 disables all 'medium' blocks)
 *          Maximum value : 255
 *          Dependencies  : None.
 */
#define  MEMORY_MANAGER_MEDIUM_BLOCK_COUNT                 2

/**
 * @brief Size of each memory blocks identified as 'medium' block.
 *
 * @details Size of each memory blocks identified as 'medium' block.
 *          Memory block are recommended to be word-sized.
 *          Minimum value : A value greater than the small pool size if defined, else 32.
 *          Maximum value : A value less than the next pool size. If only medium pool is used, this
 *                          can be any value based on availability of RAM.
 *          Dependencies  : MEMORY_MANAGER_MEDIUM_BLOCK_COUNT is non-zero.
 */
#define  MEMORY_MANAGER_MEDIUM_BLOCK_SIZE                  256

/**
 * @brief Maximum memory blocks identified as 'medium' blocks.
 *
 * @details Maximum memory blocks identified as 'medium' blocks.
 *          Minimum value : 0 (Setting to 0 disables all 'large' blocks)
 *          Maximum value : 255
 *          Dependencies  : None.
 */
#define  MEMORY_MANAGER_LARGE_BLOCK_COUNT                  1

/**
 * @brief Size of each memory blocks identified as 'medium' block.
 *
 * @details Size of each memory blocks identified as 'medium' block.
 *          Memory block are recommended to be word-sized.
 *          Minimum value : A value greater than the small &/ medium pool size if defined, else 32.
 *          Maximum value : Any value based on availability of RAM.
 *          Dependencies  : MEMORY_MANAGER_MEDIUM_BLOCK_COUNT is non-zero.
 */
#define  MEMORY_MANAGER_LARGE_BLOCK_SIZE                   1024

/**
 * @brief Disable debug trace in the module.
 *
 * @details Set this define to 1 to enable debug trace in the module, else set to 0.
 *          Possible values : 0 or 1.
 *          Dependencies    : ENABLE_DEBUG_LOG_SUPPORT. If this flag is not defined, no
 *                            trace is observed even if this define is set to 1.
 */
#define MEM_MANAGER_DISABLE_LOGS                           1

/**
 * @brief Disables API parameter checks in the module.
 *
 * @details Set this define to 1 to disable checks on API parameters in the module.
 *          API parameter checks are added to ensure right parameters are passed to the
 *          module. These checks are useful during development phase but be redundant
 *          once application is developed. Disabling this can result in some code saving.
 *          Possible values : 0 or 1.
 *          Dependencies    : None.
 */
#define MEM_MANAGER_DISABLE_API_PARAM_CHECK                0
/** @} */
/** @} */


/**
 * @defgroup iot_pbuffer_config Memory Manager Configuration
 * @{
 * @addtogroup iot_config
 * @{
 * @details This section defines configuration of memory manager module.
 */
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

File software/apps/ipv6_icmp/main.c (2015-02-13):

/* Copyright (c) 2014 Nordic Semiconductor. All Rights Reserved.
 *
 * The information contained herein is property of Nordic Semiconductor ASA.
 * Terms and conditions of usage are described in detail in NORDIC
 * SEMICONDUCTOR STANDARD SOFTWARE LICENSE AGREEMENT.
 *
 * Licensees are granted free, non-transferable use of the information. NO
 * WARRANTY of ANY KIND is provided. This heading must NOT be removed from
 * the file.
 *
 */

/** @file
 *
 * @defgroup iot_sdk_icmp_app main.c
 * @{
 * @ingroup iot_sdk_app_ipv6
 * @brief This file contains the source code for Nordic's IPv6 ICMPv6 sample application.
 *
 * This example demonstrates how Nordic's IPv6 stack can be used for sending and receiving ICMPv6 packets.
 * Sending one of four packets is triggered by user buttons on kit. LEDS blinking indicates that response has been received.
 *
 * All available packets are:
 * - Neighbor Solicitation                              | Button 1
 * - Router Solicitation                                | Button 2
 * - Echo Request to all node multicast address ff02::1 | Button 3
 * - Echo Request to remote node (Router)               | Button 4
 *
 * Note: In order to get response for Router Solicitation, peer node has to act as a Router.
 *
 *  Below is MSC explaining the data flow at ICMPv6 level.
 *
 *    +------------------+                                                +------------------+
 *    | Node             |                                                | Router           |
 *    |(this application)|                                                |                  |
 *    +------------------+                                                +------------------+
 *           |                                                                   |
 *           |                                                                   |
 *        ---|------------------------- Interface is UP  ------------------------|---
 *           |                                                                   |
 *        ---|-------------------- Button 1 has been pushed ---------------------|---
 *           |                                                                   |
 *           |[ICMPv6 Neighbor Solicitation to router's link-local address]      |
 *           |------------------------------------------------------------------>|
 *           |                                                                   |
 *           |       [ICMPv6 Neighbor Advertisement to node's link-local address]|
 *           |<------------------------------------------------------------------|
 *           |                                                                   |
 *     LEDS BLINKING                                                             |
 *           |                                                                   |
 *        ---|-------------------- Button 2 has been pushed ---------------------|---
 *           |                                                                   |
 *           |[ICMPv6 Router Solicitation to all routers multicast address]      |
 *           |------------------------------------------------------------------>|
 *           |                                                                   |
 *           |         [ICMPv6 Router Advertisement to node's link-local address]|
 *           |<------------------------------------------------------------------|
 *           |                                                                   |
 *     LEDS BLINKING                                                             |
 *           |                                                                   |
 *        ---|-------------------- Button 3 has been pushed ---------------------|---
 *           |                                                                   |
 *           |[ICMPv6 Echo Request to all nodes multicast address]               |
 *           |------------------------------------------------------------------>|
 *           |                                                                   |
 *           |                [ICMPv6 Echo Response to node's link-local address]|
 *           |<------------------------------------------------------------------|
 *           |                                                                   |
 *     LEDS BLINKING                                                             |
 *           |                                                                   |
 *        ---|-------------------- Button 4 has been pushed ---------------------|---
 *           |                                                                   |
 *           |[ICMPv6 Echo Request to router's link-local address]               |
 *           |------------------------------------------------------------------>|
 *           |                                                                   |
 *           |                [ICMPv6 Echo Response to node's link-local address]|
 *           |<------------------------------------------------------------------|
 *           |                                                                   |
 *     LEDS BLINKING                                                             |
 *           |                                                                   |
 *           -                                                                   -
 */
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

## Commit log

2014-10-02 added squall
    [squall.brd, squall.sch, squall_bom.csv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]
2014-10-02 started on rain
    rain is a temporary name
    sensor board for squall. better demo and data that way. also, there are
    some really cool sensors out now. thank you smart phones
    [rain.brd, rain.sch]
2014-10-03 rain getting close
    [rain.brd, rain.sch]
2014-10-03 rain pretty much done
    needs a name
    [rain.brd, rain.sch, rain_bom.xlsx]
2014-10-04 updated a digikey part num
    [squall.brd, squall.sch, squall_bom.xlsx]
2014-10-06 fixes: battery location and ftdi
    - rotated battery clip to hopefully not conflict with mounting holes
    - connected test on FTDI to gnd
    [squall.brd, squall.sch]
2014-10-08 updated blink
    [squall_bom.xlsx]
2014-10-08 squall updated
    [squall.brd, squall.sch]
2014-10-14 updated beacon app, fixed led
    [main.c, squall.h]
2014-10-15 add case designs
    [case.ipt, case_bottom.ipt, squall_base_case_bottom_5.stl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]
2014-10-16 added simple sniffer app
    it blinks led when adv packet comes in
2014-10-17 wrote some quick code to dump adv packets
    uses spi
2015-02-13 antenna quote
2015-03-07 Added UART BLE App
    Connected to by a phone running nRF UART app
    Echos back data transmitted from phone
2015-03-07 Commented out bug in init
    [main.c]
2015-03-12 Created basic powerblade app
    Gets data on UART and pushes to BLE advertisement
2015-03-12 squall breakout
    [squall-breakout.brd, squall-breakout.sch]
2015-03-17 updated squall breakout
    [squall-breakout.brd]
2015-03-18 Accepts only one powerblade packet at a time
2015-03-20 Advertisements start once UART data is received
2015-03-20 Turn off UART after message received
    This should save power when advertising
2015-03-22 Added GPIO for UART and Connections
2015-06-04 added device informations service application
2015-06-05 fix issue where breakout pour didn't show up
    [squall-breakout.brd]
2015-06-11 add new version of squall breakout
    [squall-breakout.brd, squall-breakout.sch, squall-breakout_bom.csv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]
2015-06-18 Fixed MAC_ADDR for squall
    [squall.h]
2015-06-18 Added twi_hw_master.c and led.c to APPLICATION_SRCS
2015-06-26 Added Pressure
2015-06-26 Made it conform to spec more but humidity value doesn't work
    [main.c]
2015-07-09 Notify works, update works, working on trigger settings. Note: humidity still doesn't work.
    [main.c]
2015-07-17 Trying to get timers to work
2015-07-21 Timers working, app almost completely working
2015-07-22 All Triggers working for Temperature and Pressure. Humidity still a mystery...
2015-08-04 added UI download service app and a sample UI
2015-08-10 UART enable/disable on timer
2015-08-16 PowerBlade no longer times out
    [main.c]
2015-10-10 Updated powerblade app to send eddystone advs
    Address points to app under development by Noah
2015-10-23 uart app merged into powerblade
    look at powerblade for uart example
2015-10-27 PowerBlade app that adds ID
2017-09-29 squall: eagle version bump (no changes)
    There are no changes in this commit, but the newer Eagle simply
    writes the file out slightly differently, so this commit serves
    to mark those changes separately.
    [squall.brd, squall.sch]
2017-09-29 squall: give all 0.1uF caps the same digikey attr
    [squall.brd, squall.sch]
2017-09-29 squall: 0.1uF digikey TR -> CT to make scripts happy
    [squall.brd, squall.sch]
2017-09-30 squall: replace obsoleted 1k resistor
    [squall.brd, squall.sch]
2017-09-30 squall: replace obsoleted 12K resistor
    [squall.brd, squall.sch]
2017-09-30 squall: run ERC/DRC on new eagle and resolve warnings
    [squall.brd, squall.sch]
2017-09-30 squall: update attributes for all parts
    [squall.brd, squall.sch]
2017-09-30 squall: updated BOM with non-obsoleted passives
    Add a readme to explain what's going on here as well.
    [squall_bom.2017-09.ConfigurationB.csv, squall_bom.2017-09.ConfigurationB.xlsx, squall_bom.LEGACY.csv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]
2017-09-30 squall: add ConfigurationB 2017 assembly files
    [squall_bom.2017-09.ConfigurationB.csv, squall_bom.2017-09.ConfigurationB.txt]

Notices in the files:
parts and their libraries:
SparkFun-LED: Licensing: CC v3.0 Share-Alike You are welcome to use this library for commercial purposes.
